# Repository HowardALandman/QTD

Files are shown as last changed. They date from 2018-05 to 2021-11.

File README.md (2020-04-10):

# QTD
Research project on Quantum Time Dilation, including theory and plans for an experiment to test it.
For theory, see the doc/QuantumTime.pdf (or .tex) file, and the references therein.
For photos, see FB album https://www.facebook.com/howard.a.landman/media_set?set=a.10153244377383214.1073741833.690298213&type=3 .

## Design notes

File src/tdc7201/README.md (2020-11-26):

# TDC7201 driver for Raspberry Pi

This project contains a python3 module for interfacing with the Texas Instruments TDC7201 Time-to-Digital-Converter chip through SPI.
As much as possible, it hides the internal implementation details (like SPI transactions, and chip registers and their field encodings) from the user.

All code is GPLv3+ licensed unless explicitly stated otherwise.

For more information on the chip, see https://www.ti.com/product/TDC7201

## Usage

```python
import tdc7201
tdc = tdc7201.TDC7201() # Create TDC object with SPI interface.
tdc.initGPIO() # Set pin directions and default values for non-SPI signals.
tdc.set_SPI_clock_speed(12500000)
tdc.on()
tdc.configure(meas_mode=2,num_stop=3,clock_cntr_stop=1,timeout=0.0005)
status = tdc.measure(simulate=True)
tdc.off()
```

## Settings

Hardware pin assignments are done in `initGPIO()`, which should only be called once.
Most other important parameters are set in the `configure()` method;
note that the chip can only be (re)configured while it is on.

## Methods

    initGPIO(enable=12,osc_enable=16,trig1=7,int1=37,trig2=11,int2=32,start=18,stop=22,verbose=False)

Assigns and initializes all the non-SPI pins.
Your actual hardware (wiring between RPi and chip) needs to match this setup.
No arguments are required, but the defaults match my prototype and are somewhat arbitrary.
You can see all assignments by calling with `verbose=True`.
Pin numbers follow `GPIO.BOARD` conventions,
i.e. they are the pin numbers on the 2x20 pin header.
Only 3 pins (`enable`,`trig1`,`int1`) are absolutely required;
the others can be skipped by assigning `None` to them.
If `osc_enable` is `None`, then there will be no signal to turn an external clock on or off; this is OK if you supply the chip clock yourself.
If `trig2` and/or `int2` is `None`, then side 2 of the chip will not work correctly, but side 1 still will.
The `stop` pin is only required if you want the Raspberry Pi to generate STOP signals for testing, i.e. if you plan to run `tdc.measure(simulate=True)`.
If you are hooked up to real signals to measure, then you can and should set `stop=None`.
The `start` pin is only required if you want the Raspberry Pi to generate a START signal; this could be hooked directly to the chip START, or used to trigger some external hardware.
Note that if you start a measurement, and the chip never sees a START signal, it will hang indefinitely waiting for one.

    on()

Takes the chip out of reset.

    configure(side=1,force_cal=True,meas_mode=2,trig_falling=False,falling=False,calibration2_periods=10,avg_cycles=1,num_stop=1,clock_cntr_stop=0,clock_cntr_ovf=0xFFFF,timeout=None)

Set up various control parameters in the chip configuration registers.

* `side` -
Which side of the chip to configure. Default is 1. 2 does not work yet.
* `retain_state` -
Default `False`.
If `True`, will ignore all other arguments, and instead use the same settings
as from the previous call to `on()`.
Behavior is undefined if there was no previous call.
* `force_cal` -
If `True`, will recalibrate the chip after every attempted measurement.
This is recommended (and, in this version, required and default).
If `False`, will only recalibrate after a "successful" measurement,
with timeouts and some other results considered unsuccessful.
(This currently does not work.)
* `meas_mode` -
Sets the measurement mode.
Mode 1 is recommended for times less than 2000 nS; mode 2 for greater.
* `trig_falling` -
If `True`, sets the chip to use falling edge on TRIG to indicate chip is ready.
The default is `False`, which has it use rising edge on TRIG.
* `falling` -
If `True`, sets the chip to trigger on falling edges of START and STOP.
The default is `False`, which has it trigger on rising edges.
* `calibration2_periods` - The number of clock cycles to recalibrate for. The allowed values are 2, 10 (hardware default), 20, and 40.
If you specify any other value, will round up (if below 40) or down (if above 40) to the next legal value.
* `avg_cycles` -
The number of measurements to average over.
The allowed values are 1, 2, 4, 8, 16, 32, 64, and 128.
The default is 1, which means no averaging.
If you use anything larger, the chip will run that many measurements and then report only the average values.
This can be useful in a noisy environment.
(Averaging does not currently work with `measure(simulate=True)`.)
* `num_stop` -
The chip starts timing on a pulse on the START pin, and then can record timings for up to 5 pulses on the STOP pin.
Allowed values are 1, 2, 3, 4, 5.
The default is 1, which means the measurement will terminate as soon as a single STOP pulse is received.
If `num_stop==3`, the measurement will terminate after recording 3 STOP pulses or after timing out, whichever comes first.
* `clock_cntr_stop = N` - If N is non-zero, the chip will ignore STOP pulses for N clock cycles after START.
* `clock_cntr_ovf = N` - The chip will end measurement ("time out" or "clock counter overflow") after N clock cycles even if `num_stop` STOP pulses have not been received.
Default (and maximum) is 65535 = 0xFFFF.
* `timeout = T` - You can also specify the overflow period as a time in seconds. For example, if T is 0.0005, the timeout period will be 500 microseconds. If both `timeout` and `clock_cntr_ovf` are specified, `timeout` wins.

Note that `clock_cntr_ovf` must be greater than `clock_cntr_stop`,
or the measurement will time out before it begins accepting stop pulses.

    measure(simulate=False,error_prefix='',log_file=None)

Runs a single measurement, waiting for the chip INT1 pin to go low indicating completion.
Will time out after 1 or more milliseconds if measurement doesn't complete.
(The `measure()` timeout must be an integer number of mS,
and is adjusted to be longer than the timeout set for the chip.)
If `simulate=True`, then generates START and/or STOP signals to send to the chip
(for testing when your actual signal source is not yet available);
this requires that the appropriate RPi pins be connected to START and/or STOP,
and that `initGPIO()` not be called with `start=None` or `stop=None` respectively.
(Simulate does not currently work with averaging.)
If it does complete, calls `read_regs24()` to download the raw register data,
and then `count_pulses()`.
The `error_prefix` string will be prepended to any error messages from this call to `measure()`;
this allows you to easily identify which call had the problem.
If `log_file` is an already-open file handle,
will write any error messages to that file instead of printing them.
Returns 0-5 for number of pulses seen, or 6-13 for various kinds of errors.

    compute_tofs()

Takes the raw register data dowloaded by the last measurement
and computes the time-of-flight for each pulse seen,
leaving them in the `tdc.tof1` to `tdc.tof5` variables.
Returns 0 to 5 for the number of pulses seen,
or 6 if an error prevented the computation.

    count_pulses()

Examines the raw register data dowloaded by the last measurement
and returns 0 to 5 for the number of pulses seen,
or 6 if an error prevented the computation.
This is about 8 times faster than `compute_tofs()`,
because it does less work.

    off()

Asserts reset and waits 1 uS for it to take effect.
This will terminate any measurement in progress,
and make the chip unresponsive to SPI until the next call to `on()`.

    clear_status(verbose=False,force=False)

Clears any set interrupt status register bits to prepare for next measurement.
This isn't supposed to be necessary, but I was having problems without doing it.
If `verbose==True`, prints detailed step-by-step results for debugging.
If `force==True`, tries to clear all IS bits even if some or all of them appear not to be set.

    set_SPI_clock_speed(speed,force=False)

Attempts to set the SPI interface clock speed to `speed` (in Hz).
Minimum legal value is 50000 (50 kHz), spec maximum is 25000000 (25 MHz),
and highest "overclocked" speed we've seen work is 33300000 (33.3 MHz).
The SPI clock is a hardware division of the CPU clock, so there are two important things to note.
(1) The exact clock speed set may be restricted (by hardware) to only certain values in that range, so you may not get exactly what you ask for.
(2) The SPI clock will slow down or speed up if the CPU clock does (for example, for thermal management, turbo mode, or due to user over- or under-clocking of the Raspberry Pi).
 The CPU (and the SPI driver, and this module) can not tell what the CPU clock speed is, so there is no way to compensate for this in software.
Therefore, it's probably a bad idea to overclock the SPI speed
if you know that your CPU will also be overclocked,
since that might result in a speed that doesn't work.
But all this should mostly be invisible to the user, as it only affects SPI communication speed, and does not affect performance of the TDC7201 measurements (unless the TDC7201 is also being clocked by some submultiple of the Pi clock, which is a really really bad idea).
* If `force=False`, values in the spec range are silent,
and overclocking up to 33.3 MHz is allowed with a warning.
If `force=True`, all speeds are allowed with a warning.
This should only be used for testing, not production.

The casual user should be able to get by with only the above methods; the following low-level methods give more detailed access to the hardware, but you'll need to know what you're doing.

    write8(reg,val)

Write a single 8-bit value to an 8-bit chip register.
This only makes sense for 8-bit registers (addresses 0 through 9).

    read8(reg)

Read a single 8-bit value from an 8-bit chip register.
This only makes sense for 8-bit registers (addresses 0 through 9).

    write16(reg,val)

Write a 16-bit value to a pair of 8-bit registers.
This only makes sense if reg is `COARSE_CNTR_OVF_H` (4), `CLOCK_CNTR_OVF_H` (6), or `CLOCK_CNTR_STOP_MASK_H` (8).

    read16(reg)

Read a pair of 8-bit registers and return them as a 16-bit value.
This only makes sense if reg is `COARSE_CNTR_OVF_H` (4), `CLOCK_CNTR_OVF_H` (6), or `CLOCK_CNTR_STOP_MASK_H` (8).

    write24(reg,val)

Write a 24-bit value to a 24-bit chip register.
This should probably never be used since those contain measurement and calibration results.

    read24(reg)

Read a 24-bit value from a 24-bit chip register.
This only makes sense for 24-bit registers (addresses 16 through 28).

    read_regs8()

Read all of the 8-bit side 1 chip registers into the `tdc.reg1` list.
(It should be possible to make this read the side 2 registers, but it doesn't yet.)
This is much faster than looping over the registers in Python.

    read_regs24()

Read all of the 24-bit side 1 chip registers (measurement and calibration results) into the `tdc.reg1` list.
(It should be possible to make this read the side 2 registers, but it doesn't yet.)
This is much faster than looping over the registers in Python.

    read_regs()

Read all of the side 1 chip registers (including measurement results) into the `tdc.reg1` list.
(It should be possible to make this read the side 2 registers, but it doesn't yet.)
This is much faster than looping over the registers in Python.
Equivalent to `read_regs8()` plus `read_regs24()`.

    print_regs1()

Print the internal copy of the side 1 chip registers. Note that, if this is not immediately preceded by `read_regs()`, the internal copy and the actual chip registers may be out of sync.

    tof_mm1(time_n)

Compute time-of-flight in seconds using Measurement Mode 1 equation.

    tof_mm2(time1,time_n,count)

Compute time-of-flight in seconds using Measurement Mode 2 equations.

    compute_tofs()

Check how many pulses we got, and compute the TOF for each pulse.

    cleanup()

Put the TDC7201 into reset, close the SPI device, and free all the GPIO pins.
Should normally only be called just before exiting.
The tdc object will still exist,
but you would have to manually reopen `tdc._spi` and set its parameters,
plus call `initGPIO()` and `on()`,
before it would be usable again.

    exit()

Clean up the SPI and GPIO pins (i.e. call `cleanup()`), and then exit.

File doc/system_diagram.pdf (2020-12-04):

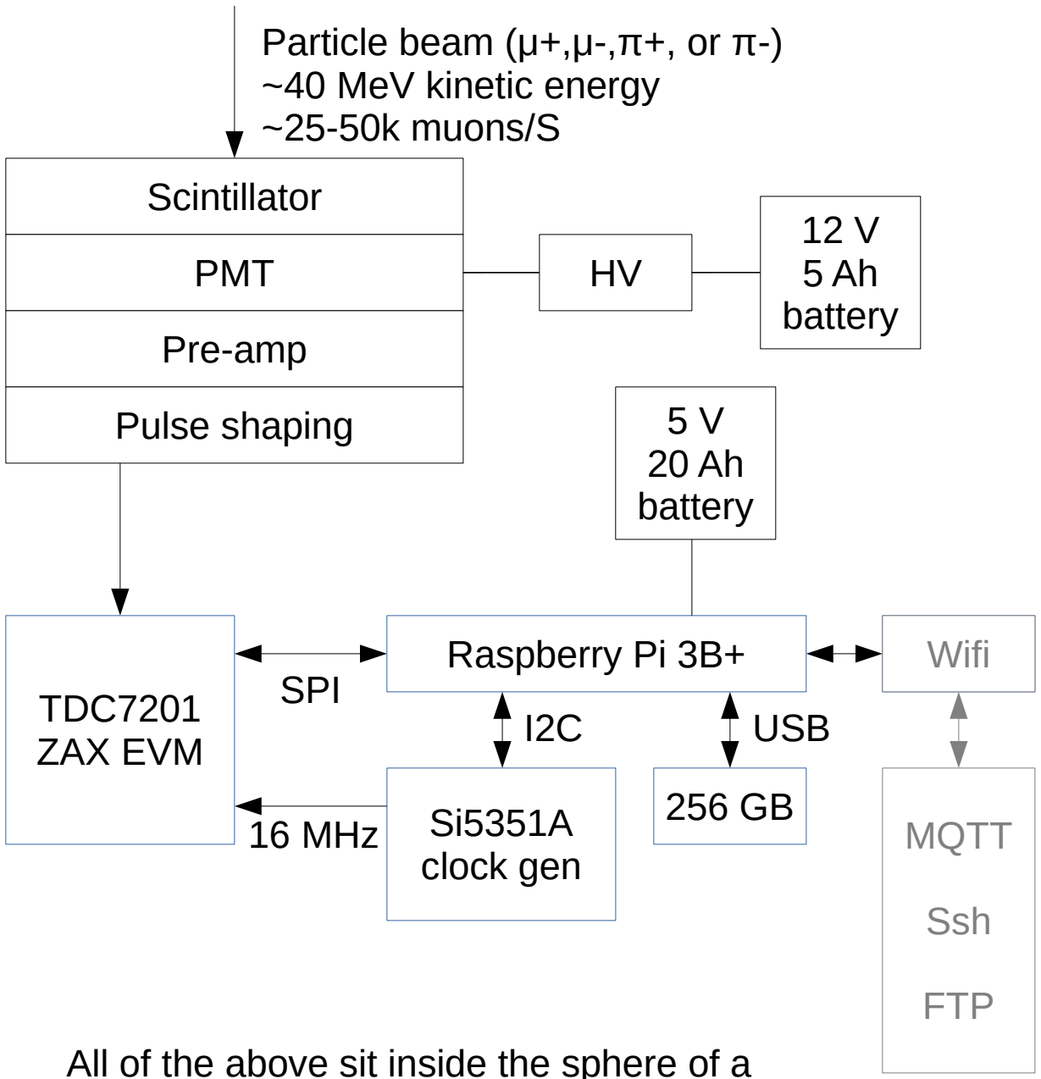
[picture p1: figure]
Particle beam (μ+,μ-,π+, or π-) ~40 MeV kinetic energy ~25-50k muons/S; Scintillator; PMT; Pre-amp; Pulse shaping; 12 V 5 Ah battery; TDC7201 ZAX EVM; Raspberry Pi 3B+; SPI; 5 V 20 Ah battery; Si5351A clock gen; 16 MHz; MQTT; Ssh; FTP; Wifi; USB

All of the above sit inside the sphere of a Van De Graaff generator, except for the external wifi router and things connected through it.

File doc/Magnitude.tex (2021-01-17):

%%%%%%%%%%%%%%%%%%%%%%% file template.tex %%%%%%%%%%%%%%%%%%%%%%%%%
%
% This is a general template file for the LaTeX package SVJour3
% for Springer journals.          Springer Heidelberg 2010/09/16
%
% Copy it to a new file with a new name and use it as the basis
% for your article. Delete % signs as needed.
%
% This template includes a few options for different layouts and
% content for various journals. Please consult a previous issue of
% your journal as needed.
%
%%%%%%%%%%%%%%%%%%%%%%%%%%%%%%%%%%%%%%%%%%%%%%%%%%%%%%%%%%%%%%%%%%%
%
% First comes an example EPS file -- just ignore it and
% proceed on the \documentclass line
% your LaTeX will extract the file if required
\begin{filecontents*}{example.eps}
%!PS-Adobe-3.0 EPSF-3.0
%%BoundingBox: 19 19 221 221
%%CreationDate: Mon Sep 29 1997
%%Creator: programmed by hand (JK)
%%EndComments
gsave
newpath
  20 20 moveto
  20 220 lineto
  220 220 lineto
  220 20 lineto
closepath
2 setlinewidth
gsave
  .4 setgray fill
grestore
stroke
grestore
\end{filecontents*}
%
\RequirePackage{fix-cm}
%
%\documentclass{svjour3}                     % onecolumn (standard format)
%\documentclass[smallcondensed]{svjour3}     % onecolumn (ditto)
\documentclass[smallextended]{svjour3}       % onecolumn (second format)
%\documentclass[twocolumn]{svjour3}          % twocolumn
%
\smartqed  % flush right qed marks, e.g. at end of proof
%
\usepackage{graphicx}
%
% \usepackage{mathptmx}      % use Times fonts if available on your TeX system
%
% insert here the call for the packages your document requires
%\usepackage{latexsym}
% etc.
%
% please place your own definitions here and don't use \def but
% \newcommand{}{}
%
% Insert the name of "your journal" with
\journalname{International Journal of Theoretical Physics}
%
\begin{document}

\title{The magnitude of electromagnetic time dilation%\thanks{Grants or other notes
%about the article that should go on the front page should be
%placed here. General acknowledgments should be placed at the end of the article.}
}
%\subtitle{Do you have a subtitle?\\ If so, write it here}

%\titlerunning{Short form of title}        % if too long for running head

\author{Howard A. Landman}
% ORCID: 0000-0003-1897-0112

%\authorrunning{Short form of author list} % if too long for running head

\institute{H. A. Landman \at
              Fort Collins, Colorado, USA \\
              Tel.: +1-970-980-1660\\
              \email{howard@riverrock.org}\\
              ORCID: 0000-0003-1897-0112           %  \\
%             \emph{Present address:} of F. Author  %  if needed
}

\date{Received: date / Accepted: date}
% The correct dates will be entered by the editor

\maketitle

\begin{abstract}
Theories unifying gravity and electromagnetism naturally give rise to the question
of whether there is a time-dilation-like effect associated with the electromagnetic 4-potential.
This notion has been widely rejected, but a handful of theories explicitly predict such an effect. \cite{Apsel1978,Apsel1979,Apsel1981,Rodrigues1983,Ryff1985,Beil1987,vanHolten1992}
At least to first order, all of them agree on its magnitude, but it has not been clear why.
Here, we show that the magnitudes of both gravitational and EM time dilations
can be computed from elementary considerations
($E=h\nu$ and $E=mc^2$)
that are independent of specific unified theories.
This demonstrates that EM time dilation must be a feature of any unified theory
that is compatible with both Special Relativity and Quantum Mechanics.
\keywords{time dilation \and gravitational \and electromagnetic \and muon \and pion \and potential}
\PACS{03.65.Sq \and 04.50.+h \and 12.10.-g \and 12.39.Pn \and 12.60.-i \and 13.35.Bv}
% \subclass{MSC code1 \and MSC code2 \and more}
\end{abstract}

\section{Introduction}
\label{intro}

From the first publication of General Relativity in 1915 to about 1930, hundreds of classical theories
were proposed attempting to unify gravity and electromagnetism \cite{Vizgin1994}.
While none of these was completely successful, some of them were very influential.
For example, Weyl's Space-Time-Matter theory \cite{Weyl1923} introduced the notion of gauge invariance,
while Kaluza-Klein theory \cite{Kaluza1921,Klein1926} used a compact 5th dimension
and was an important precursor to string theory.

Given that there is a time dilation associated with the gravitational potential in GR,
it seems reasonable to wonder whether there might be a similar time-dilation-like effect
associated with the EM potential in such unified theories.
Sadly, this question has rarely been asked, let alone answered.
David Apsel in 1978-1981 gave probably the first unified theory to explicitly predict such a time dilation \cite{Apsel1978,Apsel1979,Apsel1981},
and only a handful of subsequent papers \cite{Rodrigues1983,Ryff1985,Beil1987,vanHolten1992} mention anything similar.
At least to first order,
all of these theories agree on the magnitude of EM time dilation.

Here we show why they must.
We derive the magnitudes of both gravitational and electromagnetic time dilations
from elementary considerations ($E=h\nu$ and $E=mc^2$)
that do not depend on the machinery of GR or any specific unified theory,
and thereby demonstrate that they must be features
of any unified theory that is compatible with both Special Relativity and Quantum Mechanics.

\section{History}
\label{sec:2}

Einstein first derived gravitational time dilation in his 1907 paper on the Relativity Principle \cite{Einstein1907}.
He began in \S 18 by using Special Relativity to show that clocks at different X-positions in a reference frame accelerated in the X-direction cannot run at the same rate;
then in \S 19 used the Equivalence Principle to infer that the same thing must be true
for clocks at different values of a gravitational potential $\Phi$.
He carried out all the arguments to first order to give the linear form $T_d = 1 + \Phi/c^2$, which has since become called the weak-field approximation,
although he did note in passing that the actual formula must be
%exponential in form
$T_d = {\rm e}^{\Phi/c^2}$.
The linear approximation cannot be exactly correct because it has two problems:
it is logically inconsistent since $(1+\Phi/c^2)(1-\Phi/c^2) \ne 1$,
and there is an event horizon at $\Phi = -c^2$.
The exponential form solves both of those problems.
%We emulate his linearized first-order approach in what follows,
%but return later to briefly consider the non-linear form.

The conclusion of the 1907 argument is that acceleration
causes the rate of time flow to be a function of position
in the direction of the acceleration.
It did not matter to Einstein whether the acceleration was caused by a rocket,
or by standing on the ground in a gravitational field.
%or by being attached to a spinning disk.
Although he didn't mention it,
it is worth noting that the acceleration of a charged particle by an electric field
is not immune to this argument.
Neither are accelerations due to the weak and strong forces;
\textit{all} accelerations of a given magnitude
\textit{must} cause exactly the same time dilation.

After General Relativity in 1915 and the Schwarzschild solution in 1916,
another view became possible,
although it is still not widely appreciated.
Taking the weak field ($r_s \ll r$) and low speed ($\frac{{\rm d}r}{{\rm d}t} \ll c$) limit of the Schwarzschild metric
leaves us with the Newtonian metric
\begin{equation}
{\rm d}s^2 = ({\rm d}x^2 + {\rm d}y^2 +{\rm d}z^2 - c^2{\rm d}t^2) + (-2\frac{GM}{r}){\rm d}t^2
\end{equation}
which is just flat Minkowski spacetime plus the time dilation field.
In this metric, space is completely flat and only time is curved,
and the curved time gives geodesics that match Newtonian gravity.
This pure time dilation field appears as a $1/r^2$ ``force''.
So in the Newtonian limit of GR,
%``matter tells time how to dilate, and time dilation tells matter how to move''.
matter causes a time dilation field and the time dilation gradient causes gravitational acceleration.\footnote{This line of thought was anticipated by several early unified theories,
although they tended to describe it as a speed-of-light field rather than a time dilation field.
For example, Ishiwara wrote in 1912 that
"if the speed of light varies in space and in time,
then these variations lead to the appearance precisely there of a gravitational field." \cite{Ishiwara1912}}
The direction of cause and effect is completely reversed from the 1907 argument.

If we accept both of these arguments,
then we cannot have any acceleration without an associated time dilation gradient,
and we cannot have any time dilation gradient without an associated acceleration.
The two are inextricably linked.

\section{Gravitational time dilation from $E = h\nu$ and $E = mc^2$}
\label{sec:3}

In this section we use a new method
to derive gravitational time dilation without directly invoking relativity theory.
We assume only that particles have a rest energy associated with their mass, given by $E = mc^2$,
and a frequency associated with their energy, given by $E = h\nu$.

In a uniform gravitational field of strength $g$, raising a particle by a height $z$ requires work $mgz$. Thus, to an observer at height $0$, the total energy of the particle at height $z$ is given by $E(z) = mc^2 + mgz$ and its frequency by $\nu(z) = E(z)/h$.

However, an observer already at height $z$ would perceive the particle to have merely frequency $\nu(0) = mc^2/h$. This can only be true if the two observers have clocks running at different rates, in the ratio

\begin{equation}
T_d = \frac{\nu(z)}{\nu(0)} = \frac{E(z)}{E(0)} = \frac{mc^2 + mgz}{mc^2} = 1 + \frac{gz}{c^2}
\end{equation}

\noindent which is the weak-field approximation to GR's gravitational time dilation
(with $\Phi = gz$).
As above, the linear form can't be exactly correct but the exponential form
$T_d = {\rm e}^{gz/c^2}$ is.

This derivation appears in some sense to be quantum, since it utilizes $E = h\nu$.
But because time dilation is a dimensionless ratio, $h$ cancels out and its precise value doesn't matter.
This means that the classical ($h \to 0$) limit is exactly the same as the ``quantum'' result.
% Should perhaps discuss Colella-Overhauser-Werner experiment here.

Both this derivation and Einstein's 1907 one avoid almost all the assumptions of GR,
so each of them implies that any other theory that predicts a gravitational time dilation
must have the same relation of dilation to potential as GR.
From this viewpoint, the existence and magnitude of gravitational time dilation
cannot be viewed as a confirmation of GR specifically,
but only of a class of theories of which GR is the best known example.

%There is a curious paradox hidden in the above results.
%$\nu = E/h$ implies that in QM the (quantum phase) frequency of things is linearly proportional to their energy.
%$T_d = e^{ gz/c^2 } = e^{ mgz/mc^2 }$ implies that in GR
%the (time-dilated) frequency of things is an exponential function of their energy.
%Both formulae are widely accepted, but
%it seems obvious that they cannot both be universally true.
%Reconciling this apparent contradiction is beyond the scope of the current paper.

\section{Electromagnetic time dilation by the same method}
\label{sec:4}

We now consider the case of a particle with mass $m$ and charge $q$ in an electrostatic potential $V$.
The potential energy is $qV$, so the corresponding time dilation (to first order) must be
\begin{equation}
T_d =  \frac{mc^2 + qV}{mc^2} =  1 + \frac{qV}{mc^2}
\end{equation}
This is essentially Apsel's equation \cite{Apsel1979}
\begin{equation}
\tau_0 =  \left(1 + \frac{q}{mc^2} {\bf A}_\mu {\bf u}^\mu \right) t_0
\end{equation}
but it is achieved without any recourse to tensor calculus
or dependence on any particular unified theory.

As in the gravitational case,
the linear form cannot be completely right, and
the exponential form 
\begin{equation}
T_d = {\rm e}^{qV/mc^2}
\end{equation}
is the most obvious candidate to replace it.
But unlike in the gravitational case, here both charge and mass matter,
or more precisely the dilation is a function of the charge/mass ratio $q/m$.
This means that a simple Riemannian manifold is inadequate,
and the geometry of any unified theory has to be something more complicated,
like a Finsler space. \cite{Beil1987}

One could argue that this is not a true time dilation,
since it does not affect "time itself" (i.e. the local speed of light),
but only what gets measured by particular kinds of clocks (charged particles).
Thus, it might be more reasonable to describe it as a "potential-based time-dilation-like effect."
Much of the universal character of gravitational time dilation is absent.

However, a different kind of universality is gained,
in that the unified time dilation equation
(ignoring gravitomagnetic and magnetic terms) is
\begin{equation}\label{emtd}
T_d \approx  {\rm e}^{(m\Phi + qV) / mc^2}
\end{equation}
which treats gravity and EM equally and symmetrically.
In fact, all known and unknown forces can easily be slotted into the general equation
\begin{equation}\label{qtd}
T_d \approx  {\rm e}^{(m\Phi + qV + wW + sS + xX) / mc^2}
\end{equation}
where $w$ and $W$ are the weak force charge and potential respectively,
$s$ and $S$ the strong force ones,
and $x$ and $X$ those of some as-yet-undiscovered force
as long as it is conservative and can be represented by a potential.
This symmetry makes it more reasonable to refer to all of these effects by the same name,
"time dilation".

The claim that there are time dilations associated with all fundamental potentials
was first made by Apsel \cite{Apsel1978,Apsel1979},
but it can be considered a simple and direct consequence of QM treating all potential energies equally.
Thus we call the claim that all potentials have an associated time-dilation-like effect Quantum Time Dilation or QTD.
The weaker claim that this is at least true for EM we call Electromagnetic Time Dilation or EMTD.

\section{How to test for EMTD}
\label{sec:5}

Uncharged particles should be completely unaffected.
For a given non-zero $q$, lighter particles will be dilated more strongly than heavier particles.
The electron, being the lightest charged particle and having the highest charge/mass ratio,
should be affected the most.
But since electrons have infinite lifetime,
the only observable effect on them is the shift in phase frequency.
Although this is universally observed,
most physicists would not consider it proof of or even evidence for EMTD.

Thus, for experimental testing, we are lead to the muon.
With a mass-energy of $m_\mu c^2 = 105.7\ \textup{MeV}$,
it is still light enough to have its mean lifetime of $2.2\ \mu \textup{S}$
affected by a modest potential.
For example, a potential of 1.057 MV should alter its lifetime by about 1\%.
Traditional Van de Graaff generators have achieved voltages in the range of
0.33 to 1.4 MV per meter diameter, with 1.0 being perhaps typical,
so such a potential could be achieved
% by a Van de Graaff generator
with a sphere of about 0.7-1.1 m diameter in air,
which is well within reach of a serious hobbyist.
Apsel first proposed this kind of experiment in 1979 \cite{Apsel1979};
41 years later it still has never been performed.

For static magnetic interactions, the potential energy is $-\vec{\mu}\cdot\vec{B}$,
where $\vec{\mu}$ is the magnetic moment and $\vec{B}$ is the magnetic field,
and so to first order we get
\begin{equation}\label{mtd}
T_d =  1 + \frac{-\vec{\mu}\cdot\vec{B}}{mc^2}
\end{equation}
The muon's measured magnetic moment is
$\mu = -4.49 \times 10^{-26}\ \textup{J}/\textup{T}$.

Van Holten was the first to analyze this magnetic effect in isolation,
and thought that detection using muons might only require $5 \times 10^9\ \textup{T}$,
which could be found in the vicinity of a magnetar \cite{vanHolten1992}.
Since this is field- and not potential-based,
it should be a less controversial claim than full EMTD.
But given that the world record magnetic fields are in the range of 45--330 T,
this seems far beyond the reach of current Earth-based experiment.
%Only the electrostatic part of the effect is amenable to testing.
Indeed, to get the same 1\% level of relative time dilation between spin-up and spin-down muons,
we would need to place them in a field of
\begin{equation}
1.057\ \textup{MeV} \times \frac{1\ \textup{J}}{6.24\times 10^{12}\ \textup{MeV}} \times \frac{1\ \textup{T}}{2 \times (4.49 \times 10^{-26}\ \textup{J})} \approx 1.89 \times 10^{12}\ \textup{T}
\end{equation}
Thus, here we advocate for testing the electrostatic effect.
Dynamic interactions offer other possibilities, however \cite{Apsel1979}.

%Negative muons ($\mu^-$) bound to low-Z nuclei are also known to have lengthened lifetimes.
%The normal explanation for this is that the muon has a kinetic energy given by the quantum virial theorem,
%and an average velocity corresponding to that kinetic energy,
%and a special-relativistic time dilation corresponding to that velocity.
%However, Apsel has argued that this calculation does not match the experimental data very well,
%and that adding a (smaller) electromagnetic time dilation term gives a better fit \cite{Apsel1981}.
%If so, we may have already been seeing evidence for decades.
%The effect should be more obvious for higher Z.
%Unfortunately, as Z increases, nuclear capture by a proton begins to dominate,
%and we don't have good data on non-capture decay rates for most elements.

One characteristic of a pure time dilation is that, all other things being equal,
it must necessarily slow down (or speed up) all decay modes equally.
Since muons have 3 known decay modes \cite{PDG2014}, this can be used as a test
for whether lifetime alterations can reasonably be viewed as solely due to time dilation,
or whether other factors must be invoked.

Charged pions ($\pi^+$, $\pi^-$) have a charge-mass ratio 0.757 as large as a muon's,
and would also be reasonable for such experiments, but would require about
$0.757^{-2} = 1.745$ times as many data points to get the same statistical significance.

\section{Counterarguments}
\label{sec:6}

In this section we point out flaws in two of the main counterarguments to EM time dilation.

\subsection{Naive Gauge Invariance.}

In many physical theories,
such as classical EM and Van Holten's theory mentioned in the previous section,
everything can be expressed in terms of fields acting locally,
and potentials can be viewed as having no physical reality but being merely aids to computation.
This would of course rule out any time dilation effects from an EM potential in a field free region,
such as inside the sphere of a Van De Graaff generator.
Many physicists seem to think that this is sufficient to disprove the theory.

%The standard counterargument is that the gauge invariance of most modern theories makes the proposed effect impossible.
The problem with this viewpoint is that it is flat-out wrong.
The universe does \textit{not} have that property;
the Aharonov-Bohm effect \cite{Ehrenberg1949,Aharonov1959} suffices as a counterexample.
The importance of this is often glossed over.
For example, Jackson and Okun \cite[p.24]{Jackson2001} write:
\begin{quote}
\ldots\ gauge invariance is a manifestation of non-observability of $A_\mu$.
However integrals \ldots\ are observable when they are taken over a closed path, as in the Aharonov-Bohm effect \ldots\@
The loop integral of the vector potential there can be converted by Stokes's theorem into the magnetic flux through the loop,
showing that the result is expressible in terms of the magnetic field, albeit in a nonlocal manner.
%It is a matter of choice whether one wishes to stress the field or the potential, but the local vector potential is not an observable.
\end{quote}
Contrast this with the discussion in Feynman Vol. II \cite{FeynmanII} lecture 15-5,
where the central importance of the potential is
%emphasized: % American English
emphasised: % British English
\begin{quote}
The fact that the vector potential appears in the wave equation of quantum mechanics
(called the Schr\"{o}dinger equation)
was obvious from the day it was written.
That it cannot be replaced by the magnetic field in any easy way
was observed by one man after the other who tried to do so.
This is also clear from our example
of electrons moving in a region where there is no field and being affected nevertheless.
But because in classical mechanics \textit{\textbf{A}} did not appear to have any direct importance and,
furthermore, because it could be changed by adding a gradient,
people repeatedly said that the vector potential had no direct physical significance ---
that only the magnetic and electric fields are ``right'' even in quantum mechanics.
It seems strange in retrospect that no one thought of discussing this experiment until 1956 \ldots
The implication was there all the time, but no one paid attention to it. \ldots\ 
It is interesting that something like this can be around for thirty years but,
because of certain prejudices of what is and is not significant,
continues to be ignored.
\end{quote}
In either case, the idea that fields acting locally can explain everything is admitted to be false.

It is also worth noting that gravitational time dilation itself is locally non-observable.
There is no contradiction in claiming that a locally non-observable potential
can have a locally non-observable effect;
this is precisely how gravitational time dilation works.
However the situation is different for EM time dilation.
Since the effect is a function of the charge/mass ratio,
the time dilation experienced by (say) a muon and a human observer
is predicted to be different at the same potential.
This makes EM time dilation (and the absolute electrostatic potential) locally observable.

\subsection{CPT Invariance.}

It is often stated (e.g. in \cite{Andreev2007,Murayama2003,Sachs1987}) that CPT symmetry
guarantees that particle and antiparticle masses and lifetimes are identical.
However, this conclusion is only justified at zero potential,
or with the further assumption of naive gauge invariance (which renders potential irrelevant).
A true CPT reflection must invert all charges and magnetic moments in the universe,
which necessarily inverts all EM potentials as well.
Therefore, the CPT theorem only \textit{really} proves that a particle's mass and lifetime at 4-potential \textbf{A} must equal its antiparticle's mass and lifetime at 4-potential -\textbf{A}.
This holds true under EM time dilation, since the dilations for those two cases are identical.
Thus, the CPT theorem does not contradict the claim that particles and antiparticles will be time-dilated oppositely at a non-zero potential and that their lifetimes will differ there.
EM time dilation is completely compatible with the notion of CPT invariance.

\section{Summary}
\label{sec:7}

We reviewed two early derivations of gravitational time dilation
and gave a new elementary derivation of it.
Both the 1907 Einstein derivation and this new method
can be trivially modified to give derivations of electromagnetic time dilation as well,
which agree in magnitude with the handful of prior theories predicting such an effect.
That EMTD seems so inescapably implied,
and is yet so widely rejected,
%(with multiple counter-arguments, albeit some flawed)
points perhaps to a deep paradox in current physical thought.
Since testing for the electrostatic effect would be quite easy and cheap,
it seems worthwhile to actually perform that experiment.

%\subsection{Subsection title}
%\label{sec:2}
%as required. Don't forget to give each section
%and subsection a unique label (see Sect.~\ref{sec:1}).
%\paragraph{Paragraph headings} Use paragraph headings as needed.
%\begin{equation}
%a^2+b^2=c^2
%\end{equation}

%% For one-column wide figures use
%\begin{figure}
%% Use the relevant command to insert your figure file.
%% For example, with the graphicx package use
%  \includegraphics{example.eps}
%% figure caption is below the figure
%\caption{Please write your figure caption here}
%\label{fig:1}       % Give a unique label
%\end{figure}
%%
%% For two-column wide figures use
%\begin{figure*}
%% Use the relevant command to insert your figure file.
%% For example, with the graphicx package use
%  \includegraphics[width=0.75\textwidth]{example.eps}
%% figure caption is below the figure
%\caption{Please write your figure caption here}
%\label{fig:2}       % Give a unique label
%\end{figure*}
%%
%% For tables use
%\begin{table}
%% table caption is above the table
%\caption{Please write your table caption here}
%\label{tab:1}       % Give a unique label
%% For LaTeX tables use
%\begin{tabular}{lll}
%\hline\noalign{\smallskip}
%first & second & third  \\
%\noalign{\smallskip}\hline\noalign{\smallskip}
%number & number & number \\
%number & number & number \\
%\noalign{\smallskip}\hline
%\end{tabular}
%\end{table}

%\begin{acknowledgements}
%If you'd like to thank anyone, place your comments here
%and remove the percent signs.
%\end{acknowledgements}

% Authors must disclose all relationships or interests that 
% could have direct or potential influence or impart bias on 
% the work: 
%

\section*{Declarations}

\subsection*{Funding}
Self

\subsection*{Conflicts of interest/Competing interests}
The author declares that he has no conflict of interest.

\subsection*{Availability of data and material}
Not applicable.
Earlier versions of the paper have been available on Vixra and ResearchGate.
All plans, source code, 3D designs, etc. for a planned experiment to test this class of theories
are available and under version control at https://github.com/HowardALandman/QTD/,
including versions of this and other papers.

\subsection*{Code availability}
Not applicable.
However https://github.com/HowardALandman/QTD/src/
contains software related to the experiment.

\subsection*{Authors' contributions}
I am the sole author.
I expect to acknowledge useful discussions with others in the final version,
but that may include reviewers,
so I have not written an acknowledgements section yet.

\subsection*{Ethics approval}
Not applicable.

\subsection*{Consent to participate}
Not applicable.

\subsection*{Consent for publication}
Not applicable.

% BibTeX users please use one of
%\bibliographystyle{spbasic}      % basic style, author-year citations
%\bibliographystyle{spmpsci}      % mathematics and physical sciences
%\bibliographystyle{spphys}       % APS-like style for physics
%\bibliography{}   % name your BibTeX data base

% Non-BibTeX users please use
\begin{thebibliography}{}

\bibitem{Vizgin1994}
Vizgin, V.P. (tr. Barbour J.B.):
Unified Field Theories in the First Third of the 20th Century.
Birkh\"{a}user Verlag, Switzerland (1994)

\bibitem{Weyl1923}
Weyl, H.:
Raum$\cdot$Zeit$\cdot$Materie, 6th ed.
%Springer-Verlag (18 Apr 1923)
Springer-Verlag, Berlin Heidelberg (1923)

%\bibitem{Weyl1923a}
%Ibid., pp. 304-305

\bibitem{Kaluza1921}
Kaluza, T.:
Zum Unit\"{a}tsproblem in der Physik.
Sitzungsber. Preuss. Akad. Wiss. Berlin (Math. Phys.), 966-972 (1921)
% Sitzungsberichte der Preussischen Akademie der Wissenschaften zu Berlin
 
\bibitem{Klein1926}
Klein, O.:
Quantentheorie und f\"{u}nfdimensionale Relativit\"{a}tstheorie.
Zeitschrift f\"{u}r Physik A. 37, 895-906 (1926)
%doi:10.1007/BF01397481.

\bibitem{Apsel1978}
Apsel, D.:
Gravitational, electromagnetic, and nuclear theory.
Int. J.  of Theoretical Physics 17, 643-649 (1978)
%DOI: 	10.1007/BF00673015

\bibitem{Apsel1979}
Apsel, D.:
Gravitation and electromagnetism.
General Relativity and Gravitation 10, 297-306 (1979)
%DOI: 10.1007/BF00759487

\bibitem{Apsel1981}
Apsel, D.:
Time dilations in bound muon decay.
General Relativity and Gravitation 13, 605-607 (1981)
%DOI: 10.1007/BF00757247

\bibitem{Rodrigues1983}
Rodrigues Jr., W.A.:
The Standard of Length in the Theory of Relativity and Ehrenfest Paradox.
Il Nuovo Cimento 74 B, 199-211 (1983)

\bibitem{Ryff1985}
Ryff, L.C.B.:
The Lifetime of an Elementary Particle in a Field.
General Relativity and Gravitation 17, 515-519 (1985)

\bibitem{Beil1987}
Beil, R.G.:
Electrodynamics from a Metric.
Int. J. of Theoretical Physics 26, 189-197 (1987).

\bibitem{vanHolten1992}
van Holten, J.W.:
Relativistic Time Dilation in an External Field.
Physica A: Statistical Mechanics and its Applications 182(1-2), 279-292 (1992)

%\bibitem{vanHolten1993}
%van Holten J.W.,
%``Relativistic Dynamics of Spin in Strong External Fields.'',
%Nationaal Inst. voor Kernfysica en Hoge-Energiefysica (NIKHEF), Amsterdam (Netherlands), Sectie H.
%Preprint at arXiv:hep-th/9303124v1 (1993)

%\bibitem{Dubey2015}
%Dubey A.K., Sen A.K.,
%``Gravitational Redshift in Kerr-Newman Geometry.'',
%\textit{Astrophys Space Sci} \textbf{360}, 29 (2015)

%\bibitem{Ogonowski2012}
%Ogonowski, P.,
%``Time dilation as field.'',
%\textit{Journal of Modern Physics}, \textbf{3}, 200-207 (2012)

\bibitem{Einstein1907}
Einstein, A.:
\"{U}ber das Relativit\"{a}tsprinzip und die aus demselben gezogenenn Folgerungen.
Jahrbuch der Radioaktivit\"{a}t und Elektronik 4, 411-462 (1907)
%English translation, ``On the relativity principle and the conclusions drawn from it'',
%\textit{The Collected Papers}, \textbf{2} 433-484 (1989),
%available at \url{https://einsteinpapers.press.princeton.edu/vol2-trans/319}

\bibitem{Ishiwara1912}
Ishiwara, J.:
Z\"{u}r Theorie der Gravitation.
Phys. Zeitschrift 15, 1189-1193 (1912),
translated by Barbour in Vizgin p.39.

\bibitem{PDG2014}
Olive, K.A., et al. (Particle Data Group):
Chin. Phys. C38, 090001 (2014)
%PDF at http://pdg.lbl.gov/2014/listings/rpp2014-list-muon.pdf.

\bibitem{Ehrenberg1949}
Ehrenberg, W., Siday, R.E.:
The Refractive Index in Electron Optics and the Principles of Dynamics.
Proc. Phys. Soc. B62, 8-21 (1949)
%DOI: 10.1088/0370-1301/62/1/303

\bibitem{Aharonov1959}
Aharonov, Y., Bohm, D.:
Significance of Electromagnetic Potentials in the Quantum Theory.
Phys. Rev. 115, 485-491 (1959)
%\url{http://link.aps.org/doi/10.1103/PhysRev.115.485}
%DOI: 10.1103/PhysRev.115.485

\bibitem{Jackson2001}
Jackson, J.D., Okun, L.B.:
Historical roots of gauge invariance.
Rev. Mod. Phys. 73, 663 (2001)

\bibitem{FeynmanII}
Feynman, R.P.:
Lectures on Physics II.
Addison Wesley (1964)

\bibitem{Andreev2007}
Andreev, V.A., et al.:
Measurement of the Rate of Muon Capture in Hydrogen Gas and 
Determination of the Proton's Pseudoscalar Coupling $g_P$.
Physical Review Letters 99(3), 032002 (2007)

\bibitem{Murayama2003}
Murayama, H.:
CPT Tests: Kaon vs Neutrinos.
Physics Letters B 597(1), 73-77 (2004)
%Preprint at arXiv:hep-ph/0307127 (2003)

\bibitem{Sachs1987}
Sachs, R.G.:
The Physics of Time Reversal, 175.
U. Chicago Press, Chicago London (1987)

%\bibitem{RefJ}
%% Format for Journal Reference
%Author, Article title, Journal, Volume, page numbers (year)
%% Format for books
%\bibitem{RefB}
%Author, Book title, page numbers. Publisher, place (year)
%% etc
\end{thebibliography}

\end{document}
% end of file template.tex

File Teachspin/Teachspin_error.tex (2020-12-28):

\documentclass[12pt]{amsart}
\usepackage{geometry} % see geometry.pdf on how to lay out the page. There's lots.
\geometry{a4paper} % or letter or a5paper or ... etc
% \geometry{landscape} % rotated page geometry
\usepackage{url}
\usepackage{amsthm}
\usepackage{listings}
\usepackage{graphicx}
 \lstset{
         basicstyle=\footnotesize\ttfamily, % Standardschrift
         numbers=left,               % Ort der Zeilennummern
         numberstyle=\tiny,          % Stil der Zeilennummern
}

% See the ``Article customise'' template for come common customisations

   % The amssymb package provides \mathbb and other
   % math symbols.  The amsmath package provides sophisticated math
   % constructions.  The amsthm package provides \theoremstyle and
   % the \proof environment.
   %
   % The amsmath and amsthm packages are automatically activated by
   % \documentclass{amsart}, so there is no need to activate them here.

      \usepackage{amssymb}

   % Next we use \newtheorem to specify our theorem-like environments
   % (theorem, definition, etc.) and how to display and number them.
   %
   % Note: The \theoremstyle declarations affect the appearance of the
   % Theorems, Definitions, etc.

      \theoremstyle{plain}
      \newtheorem{theorem}{Theorem}[section]
      \newtheorem{lemma}[theorem]{Lemma}
      \newtheorem{corollary}[theorem]{Corollary}
      
      \theoremstyle{definition}
      \newtheorem{definition}[theorem]{Definition}
      
      \theoremstyle{remark}
      \newtheorem{remark}[theorem]{Remark}

   % The preamble is also a good place to define new commands and macros.
   % This part of the preamble is strictly optional according to your taste.

      \newcommand{\R}{{\mathbb R}}
      \newcommand{\nil}{\varnothing}

   % The following mysterious maneuver gets rid of AMS junk at the top
   % and bottom of the first page.
   
      \makeatletter
      \def\@setcopyright{}
      \def\serieslogo@{}
      \makeatother

\title{Suitability of the Teachspin muon lifetime device for testing QTD}
\author{Howard A. Landman}
\date{} % delete this line to display the current date

%%% BEGIN DOCUMENT
\begin{document}

\maketitle
\tableofcontents

\section{Introduction}
D. Apsel\cite{Apsel1978,Apsel1979,Apsel1981} and I\cite{Landman2012}, by entirely different methods,
both reached theories that predict the lifetime of an unstable particle can be altered by changing its energy.
I call this effect Quantum Time Dilation (QTD).
In particular, both of us predict that muon lifetime will be altered by an electrostatic potential to the extent of about 1\% per 1.05 MV.
This is clearly a testable assertion, but is sufficiently outside the mainstream of current physics research that it could be difficult to obtain funding from the usual sources to test it.
In the hope of keeping the cost of testing as low as possible,
I explore whether an inexpensive commercial student-grade muon lifetime apparatus can,
or can be modified to, provide a sufficiently accurate measure of muon lifetime to conclusively falsify or confirm these theories.

\section{The Teachspin device}
The Teachspin muon lifetime device\cite{Coan2006,Teachspin} is self-contained
except for needing an electrical outlet
and an external (Windows or Linux) computer to store and display data and run the user interface software.
It has three main components.
\subsection{The scintillator cylinder}
The primary detector comprises a solid transparent cylinder of scintillator-doped polyvinyltoluene,
a single photo-multiplier tube (PMT),
a high-voltage power supply for the PMT,
and an amplifier that converts the PMT current output to a voltage signal.
These are all contained in a light-tight aluminum shell
which keeps out external photons that could cause experimental noise or even damage the PMT,
and also keeps the high PMT voltage safely away from users.
The shell also includes an LED circuit for creating artificial light pulses to test the PMT independently of particles,
and some control knobs for the LED and the PMT.
I did not use the LED feature.

Charged cosmic ray particles, mostly muons, strike the cylinder and can generate photons in the scintillator.
Since cosmic rays have very high momenta (up to about 4 GeV/c)
and the cylinder is relatively small with low stopping power
(the manual says 120 MeV/c; our simulations using SRIM/TRIM software\cite{SRIM} gave about 62-70 MeV),
most (about 97\%) of the particles pass through the scintillator without stopping.

\subsection{The discriminator and counter}
Most of the active electronics is contained in a separate chassis.
It includes a discriminator circuit with adjustable threshold,
that can be tuned to reject pulses below the threshold.
This produces an amplified "digital" pulse if the input "analog" pulse exceeds the threshold.
The digital pulse has fixed height, but its width varies with the width of the analog pulse.

The digital pulse is then fed into an FPGA, which starts a lifetime count if one isn't already running.
Since the FPGA runs on a 50 MHz (20 nS) clock,
it is incapable of distinguishing times any shorter than that.
The count runs for 1000 clock cycles (20 $\mu$S);
if a second pulse is seen in that time, it is counted as a decay event, otherwise it is counted as a transit event.

Once a second, the number of events in the last second is written out, along with any decay events.
Each decay event, and each event summary, is communicated via USB to the computer.

\subsection{Computer and software}
Software running on the host computer writes one line of text to the data file
for each decay event, and one for each event summary.
These are the only kinds of data in the files.

For summary records, the number of events seen is recorded, followed by a timestamp.
Consecutive timestamps differ by one.

For decay events, the time between pulses in nS is written,
and is always a multiple of 20 since it is computed by multiplying the raw count from the FPGA by the nominal clock period.
It is also followed by a timestamp (number of seconds since some arbitrary starting date).
Typically there are many seconds between decay events, although it is possible to have more than one in the same second.

For the most part, in my analysis I only use the decay event records.
I did however perform some "sanity checks" on the summary records,
with interesting results described below.

\subsection{Alternatives}
Similar experiments, using different equipment,
are routinely performed at CalTech\cite{CaltechMuon}, UC Berkeley\cite{Berkeley2012}, U Mich\cite{Akerlof2009}, U Minnesota\cite{Hansen2001}, and elsewhere.
Most of these use scintillators far too large for our purposes.
However, the lab notes describe equipment configurations for discrimination, timing and counting
that could be useful.

There are other inexpensive detector options,
including several do-it-yourself ones\cite{CRDetectors},
but I don't analyze them in detail here.
The FermiLab detector\cite{FermiLabDetector} seems the most promising of these,
as it can do muon lifetime experiments and be powered by batteries.

\section{Statistical preliminaries: exponential and geometric distributions}

Before getting into the many sources of experimental noise and error,
it will be worthwhile to analyze the situation where no such problems exist.
For this purpose, we assume that we can measure a decay to infinite precision
and that all events seen are real decays.
We may also assume that the desired effect exists
and can be precisely controlled,
so that we may alter the muon lifetime at will.
Then, we are left with the purely statistical problem
of estimating the muon lifetime from a finite sample of decay events.

Even in the absence of an kind of experimental error,
the inherently random nature of exponential decay introduces a source of variance which cannot be removed.
Given the importance and simplicity of the exponential distribution,
the question of how much data must be sampled has been studied extensively.
Computing this will give us a hard lower bound for the actual experiment, as truncation, binning, noise and error can only increase this number.

Not everything in this section is actually used in the data analysis that follows later.
Topics that aren't are included in the hope that they may prove useful in related experiments.

\subsection{Maximum Likelihood Estimate and its confidence intervals}

The maximum likelihood estimate $\hat{\tau}$ for the lifetime is just the average of all the measured decay times,
\[ \hat{\tau} = \frac{1}{n}\sum_{k=1}^{n}t_k \]
with an exact $100(1-\alpha)\%$ confidence interval given by\cite{wiki_exponential}
\[ \frac{2n\hat{\tau}}{\chi^2_{1-\alpha/2,2n}} < \tau < \frac{2n\hat{\tau}}{\chi^2_{\alpha/2,2n}} \]

Using an online $\chi^2$ calculator\footnote{Using the "Calculate $X^2$ from probability $Q$ and $d$" function at \url{http://www.fourmilab.ch/rpkp/experiments/analysis/chiCalc.html} and iterating on $d$ until it converges to the desired value for $\chi^2$. This algorithm only appears to be numerically stable to about 7 decimal places, so any digits beyond that may not be meaningful.} we get Table 1.

\begin{table}[hbtp]
    \caption{Events $n$ needed to get confidence $(1-\alpha)$ at given $\chi^2$}
    \begin{tabular}{|r|r|r|r|r|r|}
        \hline
        ~                                                  & $\alpha=.02$ & $\alpha=.01$ & $\alpha=.005$ & $\alpha=.002$ & $\alpha=.001$  \\
        \hline
        5.25 MV ($\frac{\chi^2_{\alpha/2,2n}}{2n}=1.050$)  & 3459         & 4446         & 5457          & 6820          & 7866           \\ 
        2.10 MV ($\frac{\chi^2_{\alpha/2,2n}}{2n}=1.020$)  & 21303        & 27353        & 33549         & 41903         & 48316          \\ 
        1.05 MV ($\frac{\chi^2_{\alpha/2,2n}}{2n}=1.010$)  & 84786        & 108825       & 133447        & 166644        & 192125         \\ 
        525 kV ($\frac{\chi^2_{\alpha/2,2n}}{2n}=1.005$)   & 338287       & 434124       & 532287        & 664630        & 766205         \\ 
        210 kV ($\frac{\chi^2_{\alpha/2,2n}}{2n}=1.002$)   & 2111068      & 2708846      & 3321111       & 4146496       & 4779886        \\ 
        105 kV ($\frac{\chi^2_{\alpha/2,2n}}{2n}=1.001$)   & 8439886      & 10829342     & 13276595      & 16575156      & 19105704       \\
        \hline
    \end{tabular}
\end{table}

This table can be read in two ways.
First, it tells us how many data points we need to know the true lifetime to within a certain error with a given level of confidence.
For example, to know the lifetime to within 0.1\% with 98\% confidence, we need 8439886 events (first column, last row).
This is a two-tailed test, as our estimate could be either too high or too low.
For this purpose, we read the $\chi^2$ but ignore the voltage.

We can also use it to determine the number of events needed (assuming the theory is true) to produce a result with any given degree of unlikeliness in the null hypothesis (that there is no effect).
This varies with the voltage of the VDGG, since higher voltages are predicted to produce stronger effects which are easier to distinguish from random noise.
Thus, we can read it as the number of events required, at a given voltage, to produce data making the null hypothesis as unlikely as desired.
(If we pick a single direction, we have a one-tailed test and so the statistical significance level is actually $\alpha/2$.)

%Very roughly, the number of data points required goes down as $1/V^2$ and up as $-\log(\alpha)$ (guessing, need to check).
Given that higher voltages should require many fewer events, it seems desirable to get as large a voltage as practicable, so as to reduce the data requirements.
However, larger VDGGs are more expensive.
Very roughly, the sphere diameter needs to be at least 1 mm per kV (= 1 m per MV),
and the mass (and hence material cost) of the VDGG goes up as at least the cube of this.

\subsection{Sequential Probability Ratio Test}

When one is only trying to distinguish two hypotheses $H_0$ and $H_1$,
and is collecting data slowly over time,
a log-likelihood approach leads directly to the Sequential Probability Ratio Test (SPRT)\footnote{see
Gold \& Shadlen\cite{Gold2007} pages 538-542 for a nice brief exposition, particularly the sidebar on page 541.}
of Signal Detection Theory.
To the $i$th piece of evidence $e_i$ (in this case, a measured decay time) we assign a weight
\[ w_i = \log\frac{P(e_i|H_1)}{P(e_i|H_0)} \]
and our decision variable $y$, the log-likelihood after $n$ samples, is given by the simple sum
\[ y_n = \log\frac{P(e_1,e_2,...,e_n|H_1)}{P(e_1,e_2,...,e_n|H_0)} = \sum_{i=1}^n\log\frac{P(e_i|H_1)}{P(e_i|H_0)} = \sum_{i=1}^nw_i \]
The termination criterion is that we stop and say $H_1$ is true if $y_n \ge \log\frac{1-\alpha}{\alpha}$,
and we stop and say $H_0$ is true if $y_n \le \log\frac{\beta}{1-\beta}$,
and otherwise we continue to collect data.
Here $\alpha$ is the acceptable probability that we falsely conclude $H_1$ is true,
and $\beta$ the acceptable probability that we falsely conclude $H_0$ is true.

For the special case of two exponential distribution hypotheses differing only in their lifetime parameter,
($\frac{1}{\tau_0}e^{-t/\tau_0}$ versus $\frac{1}{\tau_1}e^{-t/\tau_1}$),
we have that
\[ P(e_i|H_0) = \frac{1}{\tau_0}e^{-t_i/\tau_0} \]
\[ P(e_i|H_1) = \frac{1}{\tau_1}e^{-t_i/\tau_1} \]
\[ w_i = w(t_i) = \log\frac{P(e_i|H_1)}{P(e_i|H_0)} = \log(\frac{1}{\tau_1}e^{-t_i/\tau_1}) - \log(\frac{1}{\tau_0}e^{-t_i/\tau_0}) \]
\[ = \frac{-t_i}{\tau_1} - \log(\tau_1) - \frac{-t_i}{\tau_0} + \log(\tau_0) \]
\[ = \left(\log(\tau_0) - \log(\tau_1)\right) + t_i(\frac{1}{\tau_0} - \frac{1}{\tau_1}) \]
%\begin{align*}
%& w_i = w(t_i) = \log\frac{P(e_i|H_1)}{P(e_i|H_0)} = \log(\frac{1}{\tau_1}e^{-t_i/\tau_1}) - \log(\frac{1}{\tau_0}e^{-t_i/\tau_0}) \\
%& = \frac{-t_i}{\tau_1} - \log(\tau_1) - \frac{-t_i}{\tau_0} + \log(\tau_0) \\
%& = \left(\log(\tau_0) - \log(\tau_1)\right) + t_i(\frac{1}{\tau_0} - \frac{1}{\tau_1})
%\end{align*}
The expected weight if $H_1$ is true would then be
\[ \langle w|H_1 \rangle = \int_0^{\infty} P(t)w(t)dt \]
\[ = \int_0^{\infty} \frac{1}{\tau_1}e^{-t_i/\tau_1} \left( \left(\log(\tau_0) - \log(\tau_1)\right) + t_i(\frac{1}{\tau_0} - \frac{1}{\tau_1}) \right) \]
\[ = \left(\log(\tau_0) - \log(\tau_1)\right)\int_0^{\infty} \frac{1}{\tau_1}e^{-t/\tau_1} dt + (\frac{1}{\tau_0} - \frac{1}{\tau_1}) \int_0^{\infty} \frac{1}{\tau_1} t e^{-t/\tau_1} dt \]
But the first integral is just 1 and the second integral just gives the expected value of $t$ over the entire distribution, which we know is $\tau_1$, so
\[ \langle w|H_1 \rangle =  \left(\log(\tau_0) - \log(\tau_1)\right) + (\frac{\tau_1}{\tau_0} - 1) \]

If we are able to change the muon lifetime by a fraction $\delta$, so that $\tau_1 = (1+\delta)\tau_0$, then
\[ \langle w|H_1 \rangle =  \left(\log(\tau_0) - \log((1+\delta)\tau_0)\right) + (\frac{(1+\delta)\tau_0}{\tau_0} - 1) = \delta - \log(1+\delta) \]
For $\delta=0.01$, which is what we would predict for a voltage of 1.05MV, we get
\[ \langle w|H_{1.01\tau_0} \rangle = 0.01 - 0.009950331 = 0.000049669 \]
This can be used to directly calculate the expected number of events needed to achieve any given likelihood ratio.
For example, if we want $H_1$ to be 1000 times more likely than $H_0$, we need about
\[ \frac{\log(1000)}{\langle w|H_1 \rangle} = \frac{6.907755}{0.000049669} = 139075 \pm 373 \]
decay events, where $373 \approx \sqrt{139075}$ is an estimate of the standard deviation of this number.
This is roughly comparable to the estimate 166644 given in the $\chi^2=1.01, \alpha=.002$ entry of Table 1.

\subsection{Fisher Information analysis}

We can also analyze this in terms of Fisher Information.
FI is mostly useful through the Cramer-Rao inequality
\[ (\Delta \tau)^2 \ge \frac{1}{I(\tau)} \]
in which the inverse of the Fisher Information gives a lower bound on the variance of our estimate of the lifetime $\tau$.

The FI for our purposes measures the amount of information that a single decay time $t$ carries about the unknown lifetime parameter $\tau$ upon which the probability of $t$ depends.
It is defined as the expectation of the square of the partial derivative with respect to the parameter of the log-likelihood function.
\[ I(\tau) \equiv E\left[ \left( \frac{\partial}{\partial\tau} \log f(t;\tau) \right)^2 \bigg| \tau \right] = E\left[ \left( \frac{\partial}{\partial\tau} \log \left(\frac{1}{\tau}e^{-t/\tau}\right) \right)^2 \bigg| \tau \right] \]
\[ = E\left[ \left( \frac{\partial}{\partial\tau} \left(\frac{-t}{\tau} -\log(\tau)\right) \right)^2 \bigg| \tau \right] = E\left[ \left( \frac{t}{\tau^2} - \frac{1}{\tau} \right)^2 | \tau \right] = \frac{1}{\tau^4} E\left[ (t-\tau)^2 \big| \tau \right] \]
But this last expectation is just the variance of $t$, which is $\tau^2$, so the FI for a single decay event is
\[ I(\tau) = \frac{1}{\tau^2} \]
and for $n$ decay events is just
\[ I(\tau) = \frac{n}{\tau^2} \]
so that 
\[ (\Delta \tau)^2 \ge \frac{1}{I(\tau)} = \frac{\tau^2}{n} \]
or
\[ \frac{\Delta \tau}{\tau} \ge \frac{1}{\sqrt{n}} \]
If we assume approximately Gaussian error in $\tau$ for $n$ large,
we can use this to estimate the minimum number of events required
to know $tau$ with a standard deviation $\sigma \equiv \Delta\tau < \alpha\tau$ as
\[ n \ge \frac{1}{\alpha^2} \]
From this we can see that $\alpha=.001$ gives $n \ge 1000000$.
This is not exactly comparable to the numbers calculated above,
since for $H_1$ and $H_0$ differing by 1\% it would separate the two hypotheses by 10$\sigma$.

If we apply this to the latest MuLan muon lifetime number $2.197019\pm0.000021$ $\mu$S\cite{MuLan2007},
we get $n \ge 10945334436$,
implying that it should have taken a {\em minimum} of about 11 billion muon decay events to achieve this accuracy,
even in the complete absence of any experimental error.

%\section{Exponential distribution with uniform noise}

%(NOTE THIS SECTION IS NOT RIGHT YET!)

%Now that we fully understand the behavior of a pure exponential distribution,
%and before we start considering the many sources of experimental error,
%let's briefly look at the pure exponential with a pure uniform noise source added.
%The key observation here is that,
%if we are only concerned with the {\em first} event,
%then the time to that event for a uniform distribution is in fact exponentially distributed!
%Thus (if we ignore all following events)
%we can characterize the rate parameter $\nu$ of the noise (in events per second)
%and the rate parameter $\lambda = 1/\tau$ of the decay,
%and simply add them to get the total rate.
%For $N$ starting particles, this gives us a density of events at time $t$ of
%\[ f(t;\tau,N,\nu) = Nf(t;\tau) + \nu = \frac{N}{\tau} e^{-t/\tau} + \nu \]
%Note that this is {\em not} a probability distribution, since the $\nu$ part is not normalizable.
%However if we truncate this to any finite window,
%it becomes a perfectly fine distribution and easy to normalize.

%\subsection{Fisher Information analysis}

%Here it easier to use the chain rule form of Fisher Information by noting that
%\[ \frac{\partial}{\partial\tau}\log f(t;\tau,N,\nu) = \frac{\frac{\partial}{\partial\tau} f(t;\tau,N,\nu)}{f(t;\tau,N,\nu)} 
%= \frac{N \frac{\partial}{\partial\tau} f(t;\tau,1,0)}{f(t;\tau,N,\nu)} \]
%since $\partial\nu / \partial\tau = 0$ and $N$ can be pulled outside the derivative.
%This is similar to the formula {\em without} noise,
%except for the $\nu$ term in the denominator.
%Thus the noise acts to dilute or reduce the information obtained, in a ratio of
%\[ \frac{I(\tau,N,\nu)}{I(\tau,N,0)} = \frac{f(t;\tau,N,0)}{f(t;\tau,N,\nu)} \]

%This gives us
%\[ I(\tau;N,\nu)  = E\left[ \left( \frac{N\frac{\partial}{\partial\tau} \left(\frac{1}{\tau} e^{-t/\tau} \right)}{\frac{N}{\tau} e^{-t/\tau} + \nu} \right)^2 \bigg| \tau \right] \]
%\[ = E\left[ \left( \frac{\frac{\partial}{\partial\tau} \left(\frac{1}{\tau} e^{-t/\tau} + \nu \right)}{\frac{N}{\tau} e^{-t/\tau} + \nu} \right)^2 \bigg| \tau \right]
%  = \frac{1}{\tau^4} E\left[ (t-\tau)^2 \big| \tau \right] \]
%%But this last expectation is just the variance of $t$, which is $\tau^2$, so the FI for a single decay event is
%%\[ I(\tau) = \frac{1}{\tau^2} \]
%%and for $n$ decay events is just
%%\[ I(\tau) = \frac{n}{\tau^2} \]
%%so that 
%%\[ (\Delta \tau)^2 \ge \frac{1}{I(\tau)} = \frac{\tau^2}{n} \]
%%or
%%\[ \frac{\Delta \tau}{\tau} \ge \frac{1}{\sqrt{n}} \]

%\section{Sources of error in the estimation of muon lifetime}

%\subsection{Randomness of decay}

%However, even an inexpensive educational VDGG can reach 500 kV, so that we are unlikely to have to go below the fourth row.
%Achieving .001 significance even at that level only requires about 766K events.

%We also know that "sequential sampling from an exponential population is essentially equivalent to observing a Poisson process"\cite{Sayyad1969}
%and that the variance of a Poisson process with parameter $\lambda$ is itself $\lambda$.
%(Note that $\lambda = 1/\tau$, where $\tau$ is the $1/e$ lifetime.)
%That is, for any given $\lambda$, the number of decays seen in each bin is Poisson-distributed.

%Assuming we are measuring a muon lifetime $\tau$ that has been altered by 1\%, and wish to distinguish it from the unaltered one $\tau_0$ at a significance level $\alpha$,
%we need the relative likelihood of the experimental evidence under the default hypothesis $H_{\tau_0}$ versus the time-altered hypothesis $H_\tau$ to be less than $\alpha$.
%There are several ways to approach estimating how much data this requires.

\subsection{Truncation of distribution}

It is traditional to truncate the exponential distribution on the right;
the Teachspin software does this by default at no more than 20 $\mu$S (about 9 lifetimes).
This is done both because we cannot wait forever for any single muon to decay,
and because after some time any "decay" event seen is much more likely to be noise than an actual decay.
However, it is rare that this truncation is treated exactly.

In this subsection we continue to ignore the noise issue,
but focus entirely on the problem of estimating the true distribution mean from a truncated sampling procedure.
This problem has been solved analytically by Al-Athari\cite{Al-Athari2008};
most of what follows is adapted from his paper.

Let the length of the sampling interval be $b$.
If our complete distribution is
\[ \frac{1}{\tau} e^{-t/\tau} \]
with mean $\tau$, the truncated distribution has mean
\[ \tau' = \tau - \frac{b}{e^{b/\tau} - 1} \]
where the second term essentially subtracts off the mean of the truncated portion,
weighted by the probability that a sample from the full distribution would be truncated.

Especially for large sample size $n$, we would expect the sample mean $\bar{t}$ to be less than $b/2$,
but there is some probability that this will not be true.
If it isn't, then no maximum likelihood estimator exists.
However, the chance of this occurring rapidly approaches 0 as $n\rightarrow\infty$.

The likelihood function is
\[ \frac{e^{-n\bar{t}/\tau}}{\tau^n(1-e^{-b/\tau})^n} \]
Maximizing this (or more usually its log) gives the MLE $\hat{\tau}$ for $\tau$.
(Al-Athari actually finds the MLE for $\theta = 1/\tau$,
but since he uses the log-likelihood,
the inversion becomes just a sign change and the MLE is the same either way.)
If $\bar{t} < b/2$ we are guaranteed that the MLE exists,
i.e. that the derivative of this is zero at some finite value.
(If $\bar{t} \ge b/2$, the MLE doesn't exist, but we can use $b/2$ as our estimate.
This is Al-Athari's Modified MLE (MMLE), and is equivalent to assuming a uniform distribution,
which is the limit of the exponential distribution as the lifetime goes infinite.)

Thus (skipping a few steps) we want to solve
\[ n ( \hat{\tau}' - \bar{t} ) = 0 \]
i.e. find the $\hat{\tau}'$ that correctly predicts the sample mean.
(In the full exponential case this is simply $\hat{\tau} = \bar{t}$.)
Since we know $n$ is not zero, we get $\hat{\tau}' = \bar{t}$.

Al-Athari stops here, but that doesn't give us a closed-form solution for $\hat{\tau}$ as a function of $b$ and $\bar{t}$.
Substituting back in, we get
\[ \hat{\tau}' = \hat{\tau} - \frac{b}{e^{b/\hat{\tau}} - 1} = \bar{t} \]
which can be solved numerically for $\hat{\tau}$ given $\bar{t}$ and $b$.
%\[ \hat{\tau} - \bar{t} = \frac{b}{e^{b/\hat{\tau}} - 1} \]
%\[ (e^{b/\hat{\tau}} - 1)(\hat{\tau} - \bar{t}) = b \]
%\[ e^{b/\hat{\tau}}\hat{\tau} - e^{b/\hat{\tau}}\bar{t} - \hat{\tau} + \bar{t} = b \]

\subsection{Binning and the geometric distribution}

The Teachspin timing FPGA operates on a 50 MHz (20 nS) clock $\pm$100 ppm.
Ignoring clock error for the moment,
what is the effect of putting decays into finite-width bins?

\subsubsection{Geometric distribution}

Binning converts the exponential distribution into a geometric distribution.
%(This is the only discrete distribution which is memoryless.)
If we number the bins starting at 0, the probability that a single muon will decay in bin $k$ is
\[ P(K=k) = (1-p)^kp \]
where $p$ is the probability that a muon will decay in 1 bin time if it has not decayed already.
For a given lifetime $\tau$ and bin width $b$, we have
\[ p = p(\tau,b) = \int_{t=0}^b \frac{1}{\tau}e^{-t/\tau} dt = -e^{-t/\tau}\bigg|_0^b = 1 - e^{-b/\tau} \]
For $\tau = 2031.79$ nS (our experimental result below), and $b = 20$ nS, this gives $p = 0.0097574$,
so for each bin there is about a 1\% chance that a muon will decay, and a 99\% chance it will survive.
The expected value is just
\[ \langle K \rangle = \frac{1}{p} \]
and the MLE for $p$ just the inverse of the sample mean
\[ \hat{p} = \frac{1}{\bar{K}} \]

Truncation of the geometric distribution has similar effects to truncation of the exponential distribution.
The probability that a muon which decays in one of the first $B$ bins will decay in bin $k$ is
\[ P(K=k) = \frac{(1-p)^kp}{1 - (1-p)^B} \]
which renormalizes the truncated distribution to have total probability 1.

\subsubsection{Bin offset}

The decays within a bin could of course have happened at any time during the bin window.
For very small bins, we expect that the average decay time within a bin will be slightly less than
the bin start time plus half the bin width,
since the exponential distribution is monotonic decreasing.
We can quantify this precisely using the truncated exponential analysis given above.
Let $\tau'(\tau,b)$ be the expected value of the decay time in a bin of width $b$.  Then
\[ \tau'(\tau,b) = \tau - \frac{b}{e^{b/\tau} - 1} \]
as before, except that we now expect $b/\tau$ to be fairly small.
For $\tau = 2031.79$ nS and $b = 20$ nS, this gives $\tau' = 9.9836$ nS,
which is (as expected) slightly less than 10 nS.
Thus, for an unbiased estimate with that $\tau$ and $b$, we should treat all the decays in the $k$th bin
(which spans 20$k$ to 20$(k+1)$ nS)
as if they decayed at 20$k$ + 9.9836 nS.

Failing to do this and instead using 10 nS would give a positive bias to our estimated $\tau$ of about 0.0164 nS,
or about +8 ppm.
This is small relative to the clock uncertainty of $\pm$100 ppm.

\subsection{Exponential and geometric decay are memoryless}

We note here in closing that a property unique to the exponential and geometric distributions is that they are {\em memoryless};
the probability of an event occurring does not depend on how long we have already waited for it to occur.
Another way of saying this is that they have a constant failure rate.
Because muon decay (like nuclear decay) follows an exponential decay pattern,
we do not need to be concerned with the history of the muon before it arrives in our apparatus.
Indeed, the entire experiment would not be possible without this property,
since we do not measure the {\em entire} lifetime of the muon from its creation in a pion decay while still traveling at nearly lightspeed,
but only its lifetime after coming to rest in our detector.

\section{Sources of Experimental Error}

Here are all the sources of error I can think of in the Teachspin experiment,
along with analyses of their effects and any ways of eliminating or compensating for them.

\subsection{Offset between stopping and decaying pulses}
The light in a stopping pulse is generated BEFORE the muon stops, while it is still moving.
The light in a decay pulse is generated AFTER the muon decays, mostly by the emitted electron.
Since the pulse detector works on the leading edge of both, that means it starts counting the stopping pulse too soon.
If the muon is still moving, there may be some SR time dilation that would lengthen its lifetime.

NET EFFECT: Should make measured lifetimes longer than actual ones.
Rough order of magnitude would be the width of the stopping pulse.
For my setup, the analog pulses were about 25-35 nS wide at the base, and about 4-20 nS wide at trigger level,
based on visual inspection of about a hundred pulses on a digital storage scope.
Thus we estimate a systematic bias of about $(4 + 20)/2 = 12$ nS and a $\sigma$ of no more than 8 nS for this ($\sigma^2 = 64$ nS$^2$).

SOLUTION: Discarding initial bins (see below) makes this problem go away for the stopping pulse.
For the decay pulse, we get a triggering offset of about 9 nS (from start of pulse to time of trigger) $\pm$8 nS.
We also have to add another 5.5$\pm$1.5 nS offset from the analog pulse to the digital pulse.
This gives us a total triggering correction and error of $\delta_{trig} = -14.5 \pm 9.5$ nS.

\subsection{Error due to variability in pulse size/shape}
% (2a stopping pulse, 2b decay pulse)
Since the discriminator circuit is tuned to a specific voltage level, and the leading edge has finite slope, and the size of the pulse may vary, we would expect a larger pulse to trigger slightly sooner than a smaller pulse.

NET EFFECT: Random errors in the time that the pulse is detected.
Min to max range would be somewhat less than half the typical pulse width
(soonest would be the point where the largest pulse triggers, latest would be near the middle (top) of a small pulse just barely able to trigger).
Based on the observations above, we estimate this to contribute $\sigma_p=4$ nS ($\sigma_p^2 = 16$ nS$^2$) for each pulse.

SOLUTION: Discarding initial bins removes this problem for the stopping pulse, but not for the decay pulse.

\subsection{Metastability of discriminator}
% (3a stopping pulse, 3b decay pulse)
Any time a circuit has to take an analog input and make a digital decision on it, there will be signals very close to the decision threshold that can cause the circuit to hang in a metastable intermediate state.  (This problem occurs most famously with flip-flops receiving data asynchronously to their clocks, but it can be caused by thresholds in voltage as well as in time.)  There is no theoretical upper bound to how long this hanging can occur; however, the probability of continued hanging decays exponentially with time (it is an unstable equilibrium like a pencil balancing on its point).  The exact behavior depends on circuit construction; a good circuit can make this problem very unlikely, at the cost of taking more time to make the decision.  I don't know yet what the details of the Teachspin discriminator are.

NET EFFECT: Until analyzed more closely,
we should assume that there may be occasional pulses which are effectively delayed by an entire clock cycle, or even (much more rarely) two.
Since this can happen on either pulse, it could lengthen or shrink the measured decay time.
Large and small pulses may behave differently;
if there is a difference in pulse sizes between stopping and decay pulses, we could get a net average offset, but if not the mean of this should be zero.
Although the magnitude of such an error would be on the order of $\pm10$ nS,
metastability events are very rare (1 in millions or billions), so the estimated $\sigma_{ms}$ here would be 0.1 nS or less.

\subsection{Digitization error of pulse time}
% (4a stopping pulse, 4b decay pulse)
I assume that the pulses are digitized to synchronize with a clock pulse that has 20 nS (the bin size) cycle time since the file data is reported in multiples of 20 nS.

NET EFFECT: This adds a random error which is roughly uniformly distributed over the 20 nS cycle time,
giving a systematic offset of approximately half the cycle time or 10 nS,
and adding a variance of approximately $\sigma_{dig}^2 = \frac{1}{12}(20\ nS)^2$ \cite{wikiUniform}
to a single event time.
If both stopping and decay pulses contribute this, the offsets cancel but the variances add.
For $n$ events, this variance scales linearly, so the standard deviation of the average scales as $1/\sqrt{n}$.

SOLUTION: Discarding initial bins removes this problem for the stopping pulse, but not for the decay pulse.
For either pulse, to zeroth order we can treat all decays in a bin as occurring at the center of the bin (+10 nS).
As noted earlier, a more exact correction can be computed if we know the decay time.
Since we use this number to compute the estimated decay time,
we would appear to be using circular reasoning;
however, since the effect of the decay time on the offset is small,
and the effect of the offset on the decay time is small,
in practice we can ``go around the circle'' a few times and get excellent convergence.
%IMPLEMENTATION: I currently use the zeroth order correction only (all decays are assumed to be at the center of their bin, i.e. 10 nS after the bin start for 20 nS bins).
%I plan to change this to the more exact number

IMPLEMENTATION:
Using the bin offset formula above plus the uniform approximation for variance, we take $\delta_{dig} = (\tau - \frac{b}{e^{b/\tau} - 1}) \pm \frac{10}{\sqrt{3n}}\ {\rm nS}$.
%However, bin offset is not needed when fitting to a geometric distribution.

\subsection{Inability to detect very fast decays}
Very fast decays may be difficult or impossible to detect.
Since the scintillator takes nanoseconds to emit all its light,
two pulses starting less than a few nanoseconds apart may appear to be one wide pulse.
There may also be issues throughout the analog circuitry, from the PMT to the discriminator;
each may require some time after emitting a pulse to recover and be ready for another one.
The recording computer, USB interface, and software may also impose limits.
Examination of a large output file with over 100K decay events shows zero decays in the 0 nS and 20 nS bins,
and a reduced number of decays in the 40 nS bin.
This implies that all decays shorter than about 40-50 nS are being lost.

NET EFFECT: Decays faster than some minimum time are lost.
Fitting to this data will give wrong answers.

SOLUTION: Fortunately, exponential decay is memoryless.  We can simply discard the first few bins to solve this problem.
Doing so also fixes many of the above problems.
It also has the effect of synchronizing all the muon decay start times with the beginning of the first undiscarded bin.

IMPLEMENTATION: My analysis software currently discards the first 3 bins (all decays marked as 40 nS or less).
This loses about 0.1\% of the data, which is acceptable.

\subsection{Clock jitter and drift}
The clock driving the bin sampling is not perfect, but will have some jitter.
It may also drift slightly over time due to temperature, circuit aging, power supply variation, or other causes.
For any reasonably good crystal oscillator, this will probably be much smaller than some other sources of error listed here and so negligible, but it is not zero.
Teachspin claims its clock is accurate to $\pm$100 ppm.
This could be measured by a device with a more accurate clock,
but for this report we simply assume that the clock period may both have a fixed offset of $\pm 2$ pS (100 ppm of 20 nS)
and a uniformly-distributed random jitter of the same magnitude, contributing $\frac{1}{12}(4\ {\rm pS})^2$ variance to individual decay times.
This jitter is so much smaller than the digitization error above that we ignore it.

NET EFFECT: We are left with a $\delta_{clock} = \pm10^{-4}\tau$ from our uncertainty about the actual clock period.

\subsection{False decay noise due to separate transit events close together}
This is probably the largest and most serious noise problem in the experiment.

NET EFFECT: If we assume that the transits are random, then the first transit has a uniform probability over time and the second one has the same distribution, so the probability of a false decay event from two transits is proportional to the decay window size times the square of the transit probability.

SOLUTIONS: Given the power of 2, the easiest way to reduce this noise would be to reduce transit events.  Cutting them down by a factor of 10 would reduce the false decay from this cause by a factor of 100.  One approach of course is to use a muon beam with momentum tuned to mostly stop in the detector, i.e., to increase the number of true decay events relative to the false ones.  Staying with cosmogenic muons only, detector paddles above and below the main scintillator could give signals that would allow us to detect and filter out many transit events.

It is also possible to estimate the mean number of false decays per bin and to "subtract that out" of the data in various ways.  However, this still leaves residual errors from (a) the error in estimating the mean, and (b) the variation about the mean.  An alternate statistical approach would be to leave in all the decay events (true and false), but estimate the probability that each one is true (which will depend on the bin) and weight them accordingly.  This is particularly simple in the Bayesian approach, where the log (relative) probability of the (true) event is simply added to the log (relative) likelihood of the hypothesis: we can just multiply that log event probability by the probability that the event is true and add that instead.

IMPLEMENTATION: We fit a model which has noise level as a parameter.
Both errors in fitting the average noise level, and variance from the noise, should contribute error to our lifetime estimate,
but quantifying these errors is not trivial.
It can be estimated from Monte Carlo simulation, but we haven't done that.
 
\subsection{Correlated noise}

In the previous subsection we assumed that the background noise is independent,
i.e.\ that the probability of a transit event is not correlated with other transit events.
There could be cases where this is not true.
For example, a highly energetic cosmic ray hitting part of the building structure
could generate a shower of secondary particles
and thus cause a cluster of transit events.

Since these particles would mostly still be traveling at close to lightspeed,
and light travels about a foot per nanosecond,
the time skew between two particles (in nS)
would be roughly the length difference of their paths to the detector (in feet).
We expect that most of these clusters of events would spread only a few nS,
and thus are being filtered out both by the inability of the device to measure short delays
and by our discarding of the first three 20 nS bins.
Thus, only skews of greater than 60 nS (implying either a delta-path-length of over 60 feet,
or one particle moving much slower than lightspeed)
would be able to cause false decay events.
These seem sufficiently unlikely that we can ignore them.

\subsection{Transit Time Spread in PMT}

"The delay between the absorption of a photon at the photocathode and the output pulse from the anode of a PMT
varies from photon to photon.
The effect is called 'transit time spread' or TTS.
There are three major TTS components in conventional PMTs and MCP PMTs - the emission at the photocathode, the multiplication process in the dynode system or microchannel plate, and the timing jitter of the subsequent electronics."\cite{Becker2003}

NET EFFECT:
Even in fairly slow PMTs. the TTS is rarely greater than 100 pS.
This is small relative to some of the other sources of error we have considered, but we include a $\sigma_{tts}=\pm0.1$ nS for completeness.

\subsection{Afterpulsing}

"Most detectors have an increased probability to produce a dark count pulse in a time interval of some 100 nS to some $\mu$S after the detection of a photon."\cite{Becker2003}
If we were doing single-photon detection,
this would be interpreted as a (false) decay event if it occurred within the decay window.
In this sense, afterpulsing is similar to background noise from transit events.
However, the background noise is uncorrelated, while afterpulsing is highly correlated.
Also, since we are looking for a large burst of photons rather than single photons,
a single-photon-sized event would not normally trigger the pulse detector
(our detector threshold (about 14 mV) was set well above the dark noise level of the PMT (about 1 mV)).

NET EFFECT: We expect afterpulsing to at worst slightly raise the dark noise level,
and thus not be a serious source of false decay events by itself.
However, it might slightly alter the pulse height threshold for decays at the afterpulse time.
This could have the effect of slightly increasing the number of decay events seen around the afterpulse time,
and hence slightly biasing the decay lifetime collection.

Since we have so far no details about the afterpulse behavior of the specific PMT used,
it is difficult to estimate the magnitude of any such error.

\subsection{Binomial sampling noise of $\mu^+ / \mu^-$ mixture}
All of the above would apply even if all the muons were a single type.
However, cosmogenic muons are are a mixture of muons ($\mu^-$) and antimuons ($\mu^+$)
with a slight excess of antimuons.
Values for the ratio of $\mu^+/\mu^-$ (the "charge ratio" $r$) in the literature vary from 1.08 to 1.3.

The CPT Theorem plus the assumption of EM-gauge invariance (as in the Standard Model)
would require that these have identical masses and lifetimes in vacuum,
but in matter their lifetimes differ because $\mu^-$ have an additional decay mode
of being captured by an atomic nucleus.
The best current lifetime numbers are $\tau_+ = 2197.019\pm0.021$ nS\cite{MuLan2007} for $\mu^+$ in vacuum
and $\tau_- = 2043\pm3$ nS for $\mu^-$ in carbon.

The lifetime measured in the Teachspin device is a weighted average of these two numbers,
with the weights given by the actual numbers of $\mu^+$ and $\mu^-$ detected.
However, we don't know these actual numbers, and they will vary from data set to data set.
So the expected mix of muons and antimuons will have a binomial distribution

\[ f(n_+;n,p) = \binom{n}{n_+} p^{n_+}(1-p)^{n_-} \]

where $n$ is the total number of muons,
$p = r/(r+1)$ is the {\em a priori} probability that a detected muon will be a $\mu^+$,
$n_+$ is the actual number of $\mu^+$ in our sample,
$n_- = n - n_+$ is the number of $\mu^-$.
This has mean
\[ \langle n_+ \rangle = np \]
and variance
\[ \sigma^2(n_+) = np(1-p) \]

The variance is highest when $p=1/2$, or $r=1$.
Thus we will have a higher variance if $r=1.08$ than if $r=1.3$.
For $r=1.08$ we get $p=0.519$, $\langle n_+ \rangle = 0.519n$, and $\sigma^2(n_+) = 0.2496n$.
For $r=1.3$ we get $p=0.565$, $\langle n_+ \rangle = 0.565n$, and $\sigma^2(n_+) = 0.2457n$.

NET EFFECT: Fortunately, the uncertainty in $r$ doesn't affect our $\tau$ calculations as long as we assume that $r$ is constant over time.
%The net result is that we have two additional sources of variance in our $\tau$ estimate.
We don't know the exact ratio of $\mu^+$ to $\mu^-$, since estimates in the literature vary
and may depend on altitude, latitude, and other factors.
This adds about $\pm\frac{1}{2}(0.565-0.519)(\tau_+ - \tau_-) = \pm(0.046)(154\ {\rm nS}) = \pm7.08$ nS
uncertainty to what our effective (mixed) $\tau$ should actually be in theory,
but it doesn't affect how we measure the effective $\tau$.

Still, we have the binomial sampling variance of up to $0.2496n(\tau_+ - \tau_-)^2 = 5919.51n\ {\rm nS}^2$.
(Note that this is very close to the theoretical maximum.
Even at $p=1/2$, we would see exactly 0.25 instead of 0.2496.)
This is the variance contribution for the sum of all decay times;
normalizing this down to a single average decay time gives us
\[ \sigma^2_{binom} = \frac{5919.51}{n} {\rm nS}^2 \]
\[ \sigma_{binom} = \frac{76.94}{\sqrt{n}} {\rm nS} \]
For our larger data sets, with $n$ from approximately 2330 to 20161,
this gives $\sigma_{binom} = 1.59$ nS to $\sigma_{binom} = 0.54$ nS.

\section{Analysis of actual Teachspin data}

In this section we analyze actual Teachspin data to evaluate the real-world performance of the methods developed earlier.

\subsection{The data sets}
25 pre-existing data sets were available from students in the spring 2012 Advanced Physics Lab course at CSU.
These are shown in Table 2 as A through Y.
Some of these were very short and recorded zero decay events.
Equipment settings are not recorded in the data files and were impossible to reconstruct.
I also collected 3 large data sets of my own between Sept 7th and Oct 15th, shown as Z$_1$ through Z$_3$.
For these, the threshold dial was set to 3.5, resulting in a trigger voltage of about 14 mV at the pulse detector.
\begin{table}[hbtp]
    \caption{Muon lifetime data sets}
    \begin{tabular}{|c|c|r|r|r|r|r|}
        \hline
        ~ & Date \&  Time          & Seconds & Length & Missing & Decays & Transits \\ \hline
%        2009/11/28 16:20 & 1501   & 1514      & 13        & 0            & 0              \\ 
%        2009/11/28 19:13 & 9          & 9             & 0          & 0            & 0              \\  \hline
        A & 2012/01/31 14:32 & 61          & 61            & 0           & 0            & 428              \\ 
        B & 2012/01/31 14:34 & 12          & 39            & 27         & 0            & 59              \\ 
        C & 2012/01/31 14:46 & 10062   & 166615  & 156553 & 85         & 45678            \\ 
        D & 2012/02/02 13:05 & 431255 & 431916  & 661       & 9009   & 3174760             \\ 
        E & 2012/02/14 14:01& 3238      & 3271       & 33         & 3196     & 24259    \\
        F & 2012/02/16 13:08 & 3537     & 3543       & 6            & 89         & 26983    \\
        G & 2012/02/16 14:10 & 11          & 11           & 0            & 0           & 46             \\
        H & 2012/02/23 13:44 & 1032730 & 1034759 & 2029 & 21757 & 7718681 \\
        I & 2012/03/06 13:36 & 331          & 332       & 1           & 7           & 2074 \\
        J & 2012/03/06 13:42 & 592          & 593        & 1           & 5             & 1805 \\
        K & 2012/03/06 13:52 & 348         & 348          & 0          & 1           & 2391 \\
        L & 2012/03/06 13:58 & 1384     & 1386        & 2           & 24         & 9448 \\
        M & 2012/03/06 14:21 & 646320 & 647669  & 1349    & 13902   & 3655672 \\
        N & 2012/03/22 14:08 & 127        & 128         & 1           & 4             & 913     \\
        O & 2012/03/22 14:11 & 7              & 7             & 0           & 0            & 42   \\
        P & 2012/03/22 14:15 & 4358      & 4367       & 9           & 20034   & 213503 \\
        Q & 2012/04/05 15:35 & 473249 & 474128 & 879       & 0           & 810 \\
        R & 2012/04/19 13:22 & 9191    & 9570      & 379       & 89          & 44903  \\
        S & 2012/04/24 14:41 & 167083 & 167379 & 296      & 2586     & 1155656 \\
        T & 2012/04/26 13:21 & 4765    & 4772       & 7           & 81          & 22537 \\
        U & 2012/04/26 15:00 & 5419   & 5427      & 8            & 86         & 28342 \\
        V & 2012/05/01 15:32 & 1469   & 1471       & 2            & 21         & 7473 \\
        W & 2012/05/03 13:14 & 5           & 5             & 0            & 0            & 18 \\
        X & 2012/05/03 13:17 & 9583    & 9598      & 15          & 178       & 68048 \\
        Y & 2012/05/03 15:57 & 430651 & 431341 & 690      & 7128    & 2981465 \\  \hline
%        Z0 & 2012/08/27 13:09 & 159        & 160        & 1           & 2           & 986 \\
%        MD & 2012/08/27 13:12 & 784008 & 11404444 & 10620436 & 13111 & 5446296 \\
        Z$_1$ & 2012/09/07 12:05 & 485774 & 486625 & 851      & 6726    & 2939733 \\
        Z$_2$ & 2012/09/14 11:32 & 736361 & 737832 & 1471    & 10454 & 4463818 \\
        Z$_3$ & 2012/09/28 12:04 & 1466550 & 1468753 & 2203    & 21502 & 8939629 \\
        \hline
    \end{tabular}
\end{table}

\subsection{Missing time\-stamps}
Some internal inconsistencies were noted in the files,
particularly missing time\-stamps.
One line is supposed to be written every second recording the number of transit events seen in that second;
the last field in the line is a timestamp in seconds.
The timestamps should be consecutive,
and the number of them (shown in the table as "Seconds")
should equal the last time stamp minus the first timestamp plus one (shown as "Length").
The difference "Missing" (= Length - Seconds) gives the number of missing timestamps.

Most of the time, only a small fraction of the data (less than 2\%) is missing.
This kind of effect might happen if the counter clock were slower than the PC clock,
and the timestamps were generated by the PC.
In that case we would expect the fraction of missing seconds to be consistent across all data sets,
because it would be roughly equal to $1 - \frac{PCClockPeriod}{CounterClockPeriod}$.
However, this is not what we see in the given data sets.
The fraction missing, and their locations in the files, seem more random than that.

This could perhaps be explained by occasional software glitches dropping a data packet,
possibly caused by the PC software sometimes not getting enough CPU time and a failure to implement a reliable communications protocol with adequate hardware buffering and handshaking.
However, in data set C more than 90\% of the data is missing,
which cannot easily be explained in this way.
Most of the missing data in C comes from a single gap in timestamps between 1328055282 and 1328210272,
accounting for 154991 of the 156553.
However, there are still many individual single missing timestamps.
Thus it seems likely that there are at least 2 or 3 different causes of data dropout problems.
Debugging these problems would be time-consuming and is beyond the scope of the present report.

This discrepancy complicates the data analysis,
especially as regards the average number of transit events per second,
which is one important way of estimating the background noise.
It is probably fairest to divide Transits by Seconds to estimate this,
since any transit events in the lost seconds would not have been counted.

\subsection{Gradient descent: Design}

In a Machine Learning approach,
we could simply treat the data as being modeled by 3 parameters:
the decay lifetime $\tau$, the initial number of decaying muons $N$,
and the background noise level $\nu$.
A minimum-variance fit to the data would give us estimates of all 3 parameters.

A more detailed procedure is as follows:
%We first give a rough estimate of the background noise level $\nu$
%as just the total number of transit events, divided by the total number of seconds,
%times the bin width $b = 20$ nS in seconds (.00000002).
We estimate the initial decay lifetime $\tau$,
% as 2.2 $\mu$S,
the initial population $N$,
% as the total number of decay events,
and the initial background noise $\nu$.
% as 0 (no noise).
The hypothesis for each bin $k$ is then
\[ H(N,\tau,\nu,k) =  N(1-p)^k p + \nu \]
 where $p = p(\tau) = 1 - e^{-b/\tau}$ as above, and $\nu$ is the expected number of false decay events in a single bin.
We want to find the $N,\tau,\nu$ that minimizes the error or variance
\[ V = \sum_{k=0}^{B-1} (H(N,\tau,\nu,k) - Y(k))^2 \]
where $Y(k)$ is the actual data for bin $k$ and $B$ is the number of bins.

Since this is nonlinear in $p$ and $\tau$, direct solution of the equations using linear algebra is not possible.
A gradient descent approach might work well.
To apply it though, we need the following partial derivatives (arguments to Y and H suppressed for brevity):
\[ \frac{\partial V}{\partial N} = \sum_{k=0}^{B-1} 2\left(H-Y\right)\frac{\partial H}{\partial N} = 2 p \sum_{k=0}^{B-1} (H-Y)(1-p)^k \]
using the chain rule.
\[ \frac{\partial V}{\partial \tau} = \sum_{k=0}^{B-1} 2\left(H-Y\right) \frac{\partial H}{\partial p} \frac{\partial p}{\partial \tau} \]
\[ = 2N\sum_{k=0}^{B-1} (H-Y)( (1-p)^k - k(1-p)^{k-1}p ) e^{-b/\tau} \frac{b}{\tau^2} \]
\[ = 2N \frac{b}{\tau^2} \sum_{k=0}^{B-1} (H-Y)( (1-p)^{k+1} - k(1-p)^{k}p ) \]
since $ e^{-b/\tau} = (1-p)$, and
\[ \frac{\partial V}{\partial \nu} = \sum_{k=0}^{B-1} 2\left(H-Y\right)\frac{\partial H}{\partial \nu} = 2\sum_{k=0}^{B-1} (H-Y) \]
\[ = 2B(\frac{1}{B}\sum_{k=0}^{B-1} H - \frac{1}{B}\sum_{k=0}^{B-1} Y) = 2B(\bar{H} - \bar{Y}) \]
This last equation is particularly simple: it tells us that the minimum variance value of $\nu$,
given some fixed $N$ and $\tau$, is the value that makes the average $H$ equal the average $Y$.
So it might also be possible to use a hybrid approach,
where we use gradient descent at each step for $N$ and $\tau$, and then solve exactly for the best $\nu$.

\subsection{Gradient descent: Implementation and results}

We implemented the above approach in GNU Octave, a Matlab clone\cite{GNUOctave,wikiOctave}.
Convergence on the $N$ and $\tau$ terms was much slower than on the $\nu$ term.
By itself, $\nu$ converged in 5 to 10 iterations as long as the descent scaling factor $\alpha$ was 0.005 to 0.009.
At $\alpha=0.01$, it showed signs of overshooting and oscillation; much higher than that and it failed to converge at all.
On the other hand, at $\alpha=0.009$, $N$ and $\tau$ took a few million iterations to converge;
a higher $\alpha$ could have sped this up.

We ran this process for 10 million iterations with $\alpha=0.009$ on each of the data sets in Table 2 that had more than 1000 decays,
resulting in Table 3.
The last row (labeled Z$_{all}$) is the union of my 3 data sets.
\begin{figure}[hbtp]

% This next "rubric" seems silly, but also works as long as included in a figure environment
%\centerline{
%\pdfximage
%width 5 in {data/ZZ.pdf}
%\pdfrefximage
%\pdflastximage }
\end{figure}
Each run took about 82 minutes on a MacBook Pro 5.1 (2.53 GHz Intel Core 2 Duo) with 4 GB memory.
Only 1 of the 2 processors was utilized, since Octave does not multiprocess.
The first 3 bins of each data set were discarded (for reasons discussed above),
leaving 997 bins each still 20 nS wide,
with all the remaining decay times effectively reduced by 60 nS to match.
This preprocessing was done by a Perl script,
which wrote out a text file that could be read into Octave as an array.
The array contained only the number of decay events for each bin,
and not any individual events;
this collective data is what the gradient descent attempted to fit.
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

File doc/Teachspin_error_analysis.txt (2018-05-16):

John, Stuart,

Here are all the sources of error I can think of in the Teachspin experiment.

(1) Decay offset due to different natures of stopping and decaying events.
The light from the stopping event is generated BEFORE the muon stops, while it is still moving.  Since the pulse detector works on the leading edge of both, that means it starts counting the lifetime too soon.  If the muon is still moving, there may be some SR time dilation that would lengthen its lifetime.
The light from the decaying event is measured AFTER the muon decays and is mostly generated by the electron produced.
NET EFFECT: Should make measured lifetimes longer than actual ones.  Rough order of magnitude would be the width of the stopping pulse.

(2) Error due to variability in pulse size/shape. (2a stopping pulse, 2b decay pulse)
Since the discriminator circuit is tuned to a specific voltage level, and the leading edge has finite slope, and the pulse shape may vary, and the size of the pulse may vary, we would expect a larger pulse to trigger slightly sooner than a smaller pulse.
NET EFFECT: Random errors in the time that the pulse is detected.  Min to max range would be somewhat less than half the typical pulse width (soonest would be the point where the largest pulse triggers, latest would be near the middle (top) of a small pulse just barely able to trigger).
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

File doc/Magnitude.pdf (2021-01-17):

International Journal of Theoretical Physics manuscript No. (will be inserted by the editor)

### The magnitude of electromagnetic time dilation

Howard A. Landman

Received: date / Accepted: date

Abstract Theories unifying gravity and electromagnetism naturally give rise to the question of whether there is a time-dilation-like effect associated with the electromagnetic 4-potential. This notion has been widely rejected, but a handful of
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

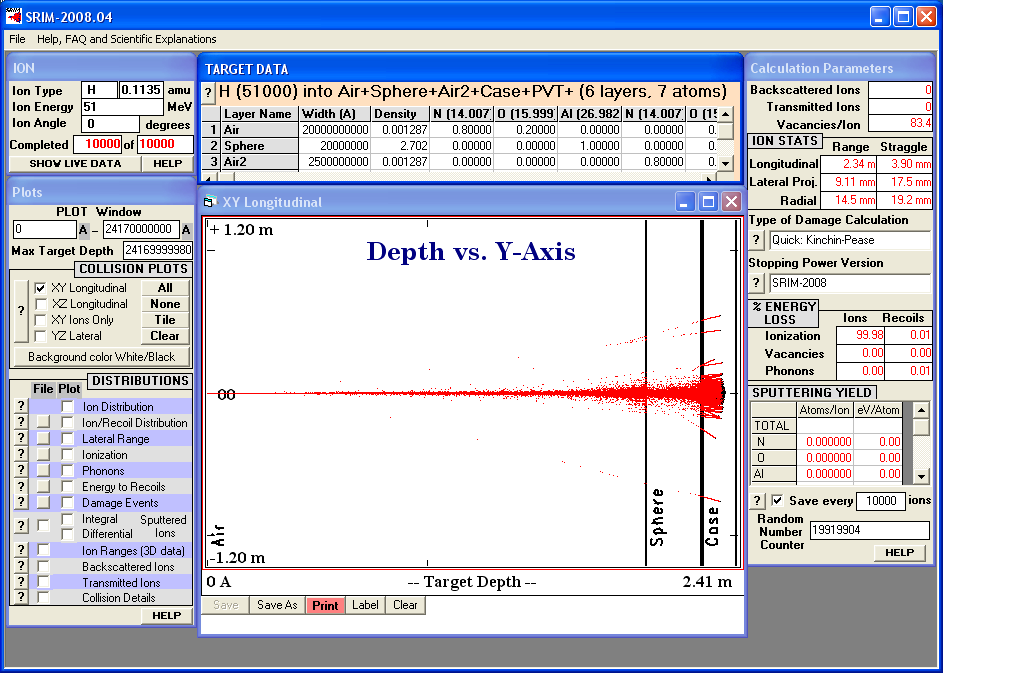
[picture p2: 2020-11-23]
Teachspin/TRIM_sphere.PNG

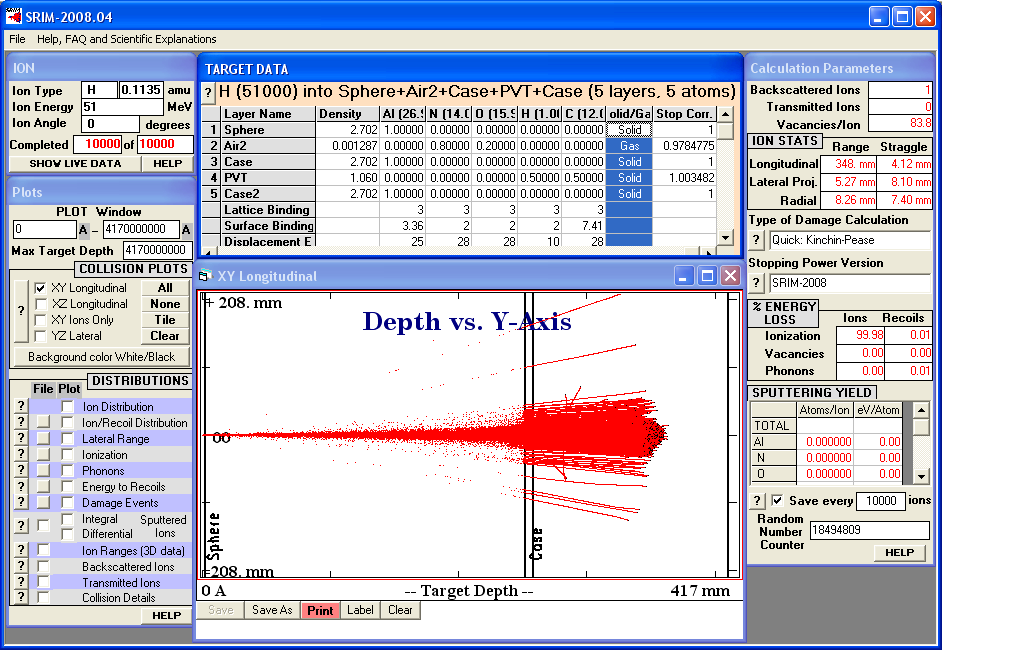
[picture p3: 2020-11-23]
Teachspin/TRIM_TeachSpin.PNG

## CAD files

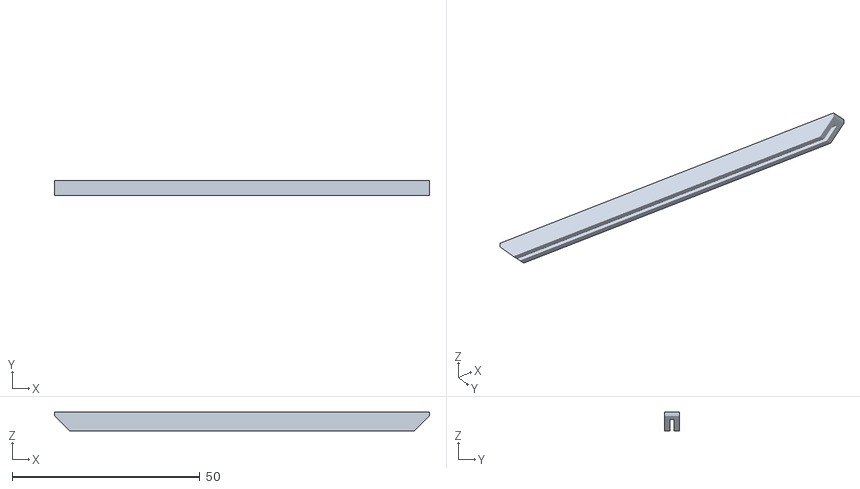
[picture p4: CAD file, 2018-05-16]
3D_printing/detector_slot.stl
100.0 x 4.00 x 5.00

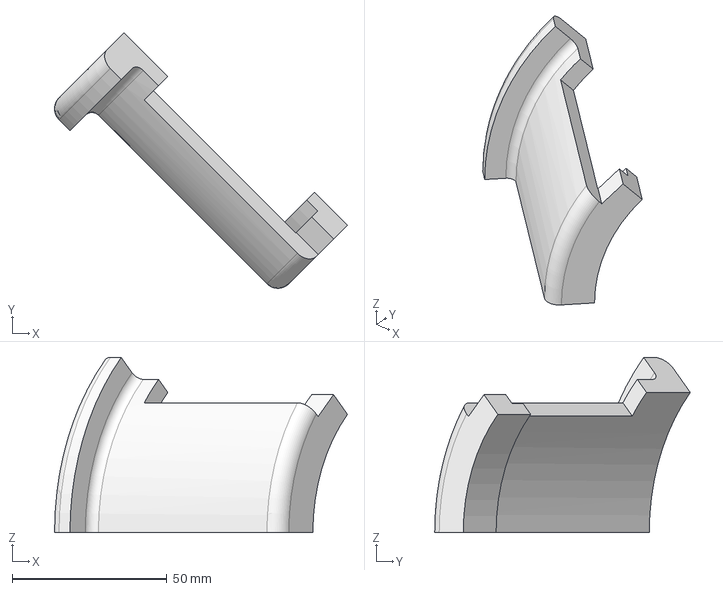
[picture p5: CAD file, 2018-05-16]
3D_printing/sphere_support_cyls4_w4.FCStd
94.7 x 82.6 x 56.6 mm

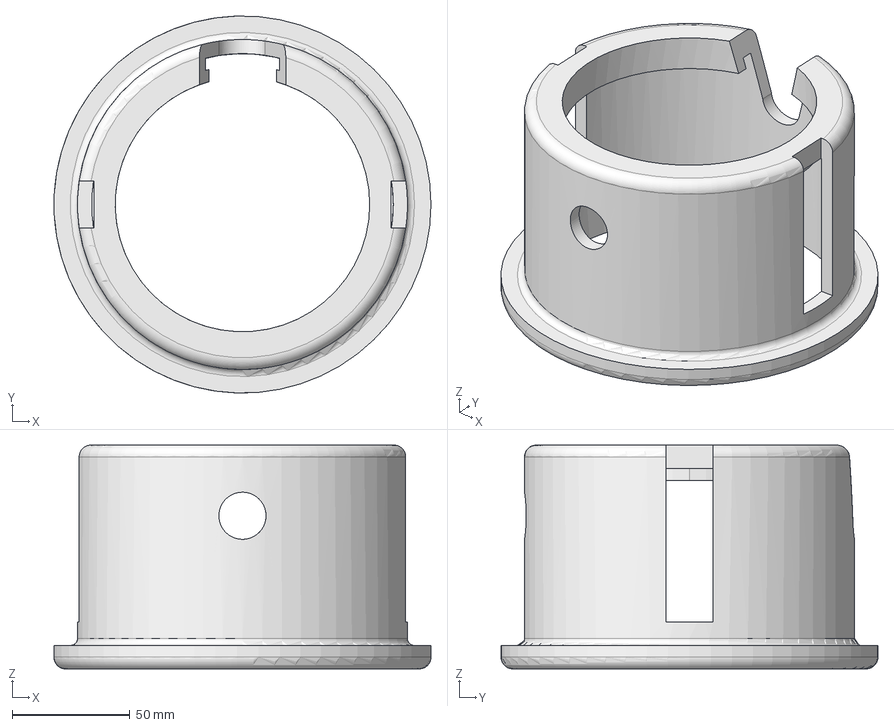
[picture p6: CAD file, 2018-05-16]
3D_printing/sphere_support_cyls4.FCStd
160.0 x 159.9 x 95.0 mm

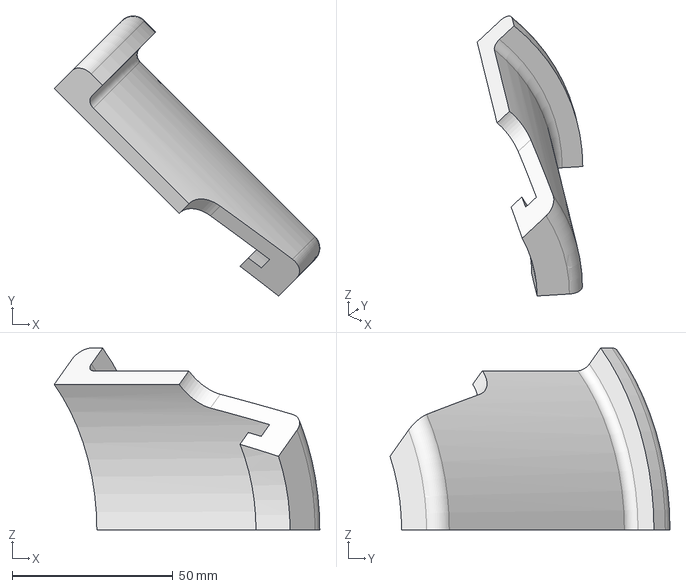
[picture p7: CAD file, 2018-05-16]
3D_printing/sphere_support_cyls4_w1.FCStd
82.6 x 87.1 x 56.6 mm

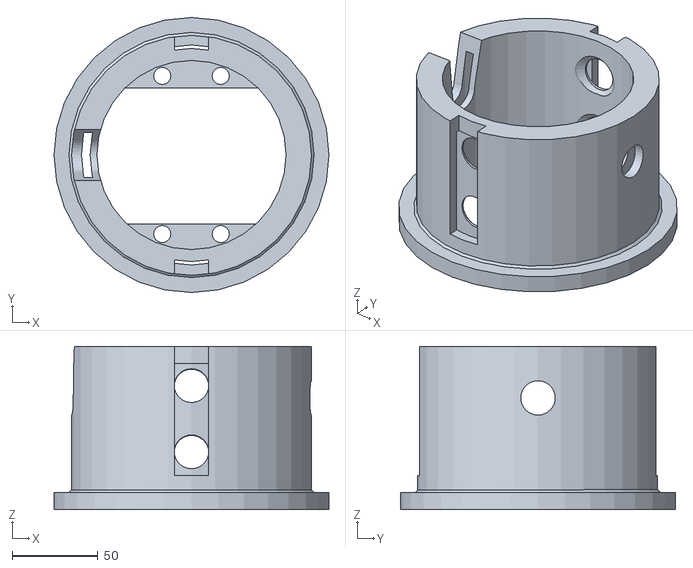
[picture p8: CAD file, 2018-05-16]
3D_printing/sphere_support.stl
160.0 x 160.0 x 95.0

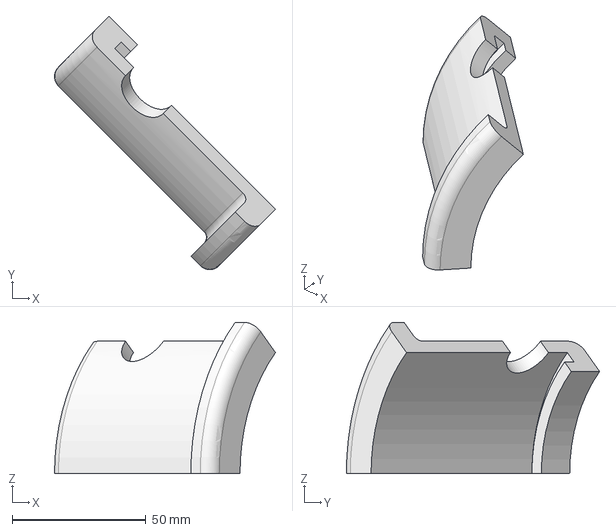
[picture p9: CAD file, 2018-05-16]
3D_printing/sphere_support_cyls4_w5.FCStd
82.6 x 94.7 x 56.6 mm

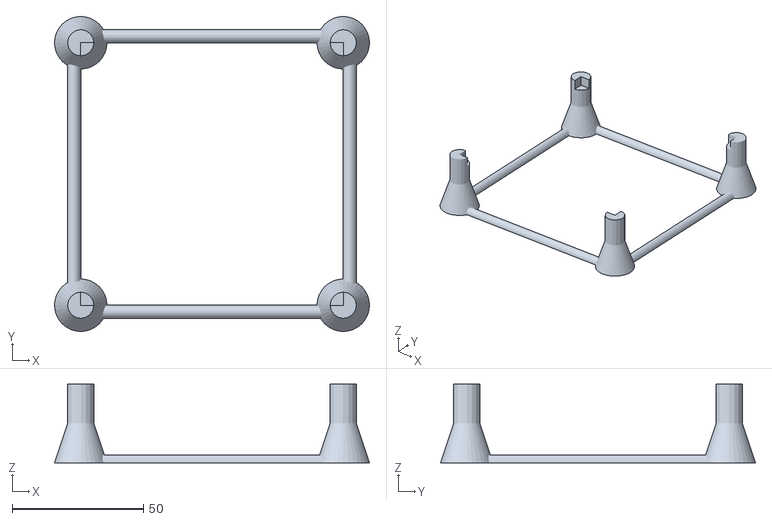
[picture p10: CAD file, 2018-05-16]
3D_printing/plate_support_25_mm.stl
120.0 x 120.0 x 30.0

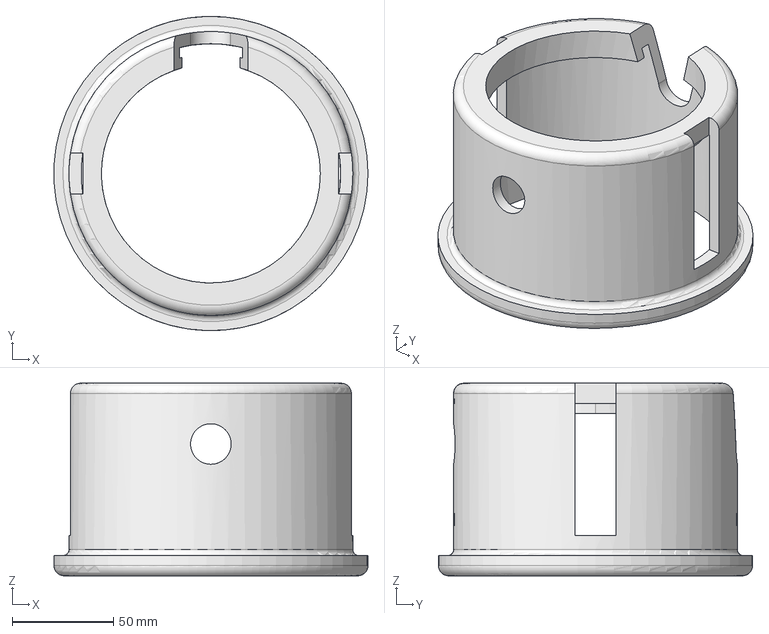
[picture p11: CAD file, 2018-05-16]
3D_printing/sphere_support_cyls3g.step
154.9 x 154.9 x 95.0 mm

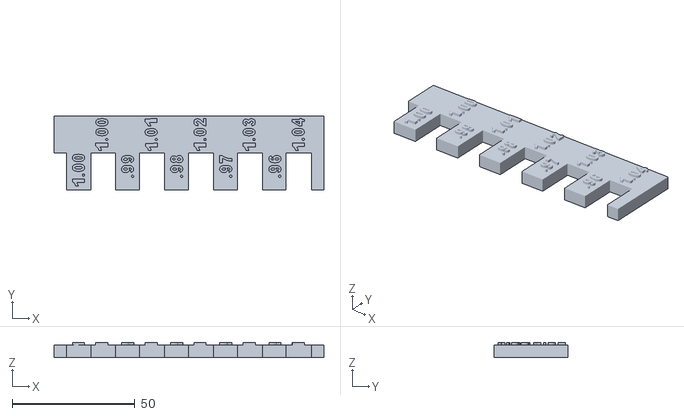
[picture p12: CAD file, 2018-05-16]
3D_printing/tolerance_vernier.stl
110.0 x 30.0 x 6.00

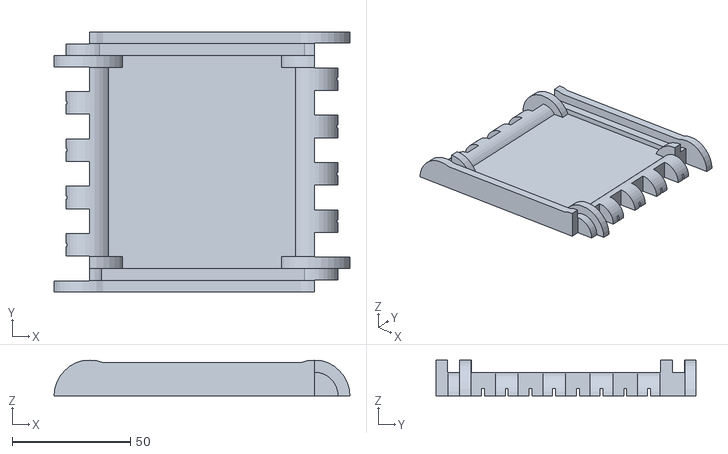
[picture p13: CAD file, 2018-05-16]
3D_printing/detector_side.stl
125.0 x 110.0 x 15.0

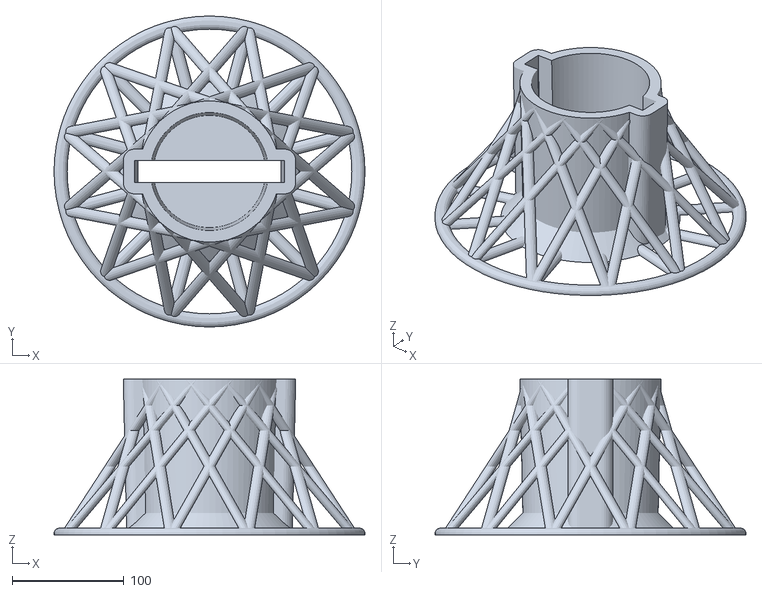
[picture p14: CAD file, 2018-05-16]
3D_printing/QTD Foam Support.stl
277.8 x 277.8 x 139.0

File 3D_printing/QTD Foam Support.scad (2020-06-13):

// Support structure for 1/4" foamboard QTD experiment base
height=139;     // 160 to equator, minus 15 for flange, minus 6 for foam thickness
angle=30;
r_max = 133;    // Lulzbot Taz bed size is nominally 280 x 280, so r_max < 140.
                // 135 was too big (slicer wouldn't accept). 134 was marginal.
r_mink = 5;     // Radius of rounding in minkowski.
r_ring = r_max - r_mink; // Outside radius of ring before minkowski
r_contact = 63; // radius of "top" surface that contacts sphere support
fillet = 3;     // radius of rounding in negative minkowski

// Now we need to compute the strut transform parameters.
// This is a little tricky.
r_strut = 5;
// Aim for making the top of the strut just tangent to the inner cylinder.
// But adjust for strut diameter.
// Since the tangent point makes a right triangle with the center and strut point,
// we can compute all the lengths.
// h = strut base to center = r_ring - 1
strut_h = r_ring - 1;
// b = tangent to center = r_contact - r_strut
strut_b = r_contact - r_strut;
// Given the hypotenuse and one side, compute the remaining side.
strut_a = sqrt(strut_h*strut_h - strut_b*strut_b);
// Find sin and cos of angle in base plane at strut base.
strut_cos = strut_a / strut_h;
strut_sin = strut_b / strut_h;
// Compute the necesary deltas in X and Y.
strut_dx = strut_a * strut_cos;
strut_dy = strut_a * strut_sin;
// Compute the corresponding transform parameters.
strut_cx = strut_dx / height;
strut_cy = strut_dy / height;
// Transform for struts tilted left.
ML = [[  1,   0, -strut_cx, 0  ],
      [  0,   1, -strut_cy, 0  ],
      [  0,   0, 1,         0  ],
      [  0,   0, 0,         1  ]] ;
// Transform for struts tilted right. Same as left, except for sign of Y.
MR = [[  1,   0, -strut_cx, 0  ],
      [  0,   1,  strut_cy, 0  ],
      [  0,   0, 1,         0  ],
      [  0,   0, 0,         1  ]] ;
      
// Transform to taper central slot
// It needs to be 133+ at "top" here and 128+ at "bottom".
// This changes over "height" variable.
// So X=64 needs to scale to X=67
slot_x_bot = 128;
slot_x_top = 134;
slot_y = 21;    // 20 was a tight fit before acetone vapor bath, jammed after.
slot_delta_x = (slot_x_top - slot_x_bot) / 2;
slot_slope = slot_delta_x / height;
MSL = [[  1,   0, slot_slope, 0  ],
      [  0,   1, 0,          0  ],
      [  0,   0, 1,          0  ],
      [  0,   0, 0,          1  ]] ;
MSR = [[  1,   0, -slot_slope, 0  ],
      [  0,   1, 0,          0  ],
      [  0,   0, 1,          0  ],
      [  0,   0, 0,          1  ]] ;

hpf = height + fillet;  // Use increased height for things that will be filleted down.

difference() {
    // main body as a solid
    difference() {
        cylinder(r=140,h=hpf+1);    // Maybe h=height or height+1 would be OK?
        minkowski() {
            difference() {
                cylinder(r=143,h=hpf+2);
                union() {
                    // main cylinder is slightly conical to match slope of bracket hull
                    cylinder(r1=r_contact-slot_delta_x+fillet,r2=r_contact+fillet,h=hpf,$fa=5);
                    //translate([0,0,height-40]) cylinder(r1=0,r2=69,h=40,$fa=5);
                    // flare at base
                    cylinder(r1=80+fillet,r2=0,h=80+fillet,$fa=5);
                    //cylinder(r=135,h=2);
                    // bracket hull
                    hull() {
                        hull_x = slot_x_bot / 2;
                        hull_y = slot_y / 2;
                        multmatrix(MSL) translate([ hull_x, hull_y,0]) cylinder(r=10+fillet,h=hpf);
                        multmatrix(MSL) translate([ hull_x,-hull_y,0]) cylinder(r=10+fillet,h=hpf);
                        multmatrix(MSR) translate([-hull_x, hull_y,0]) cylinder(r=10+fillet,h=hpf);
                        multmatrix(MSR) translate([-hull_x,-hull_y,0]) cylinder(r=10+fillet,h=hpf);
                    }
                    // base
                    minkowski() {
                        union() {
                            // base ring
                            difference() {
                                cylinder(r=r_ring,h=1,$fa=5);
                                cylinder(r=r_ring-2,h=10,center=true,$fa=5);
                            }
                            // base radial struts
                            for(a = [angle/2 : angle : 180]) {
                                rotate([0,0,a]) translate([0,0,0.5]) cube([2*strut_h,1,1],center=true);
                            }
                        }
                        // hemisphere to round everything
                        intersection() {
                            sphere(r=r_mink+fillet,$fa=10);
                            cylinder(r=r_mink+fillet+1,h=r_mink+fillet+1);
                        }
                    }
                    // Hyperboloid struts
                    for(a = [angle/2 : angle : 360]) {
                        rotate([0,0,a]) union() {
                            // left leaning struts
                            multmatrix(ML) {
                                translate([strut_h,0,0]) cylinder(r=5+fillet,h=height,$fa=10);
                            }
                            // right leaning struts
                            multmatrix(MR) {
                                translate([strut_h,0,0]) cylinder(r=5+fillet,h=height,$fa=10);
                            }
                            // hemisphere at join
                            //translate([strut_h,0,0]) intersection() {
                            //    sphere(r=8,center=true,$fa=10);
                            //    cylinder(r=11,h=11);
                            //}
                        }
                    }
                }
            }
            sphere(r=fillet);
        }
    }
    // things to cut out
    union() {
        // slot for metal straps
        multmatrix(MSL) { cube([slot_x_bot,slot_y,300],center=true); }
        multmatrix(MSR) { cube([slot_x_bot,slot_y,300],center=true); }
        // central cylindrical hole
        translate([0,0,10]) cylinder(r1=53-slot_delta_x,r2=53,h=height,$fa=5);
    }
}

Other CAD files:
3D_printing/sphere_support_cyls4_w6.FCStd
3D_printing/sphere_support_cyls4_w3.FCStd
3D_printing/sphere_support_cyls4_w2.FCStd
3D_printing/sphere_support_cyls3g.FCStd
3D_printing/sphere_support_cyls4_w1.stl
3D_printing/sphere_support_cyls4_w2.stl
3D_printing/sphere_support_cyls4_w3.stl
3D_printing/sphere_support_cyls4_w4.stl
3D_printing/sphere_support_cyls4_w5.stl
3D_printing/sphere_support_cyls4_w6.stl

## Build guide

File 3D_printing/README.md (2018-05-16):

# 3D Printing
Some parts of the experimental equipment will be 3D printed.
This directory holds the relevant files, but the original source may be elsewhere.

## Plate support (25 mm)
### A first experiment, just a stand for a 10 cm plate
Source: https://www.tinkercad.com/things/kLAUk3VosVy
Print data: plate_support_35_mm.stl
Mass (HIPS): 15 grams

## Detector slot
### A piece of the detector frame, intended to support one edge of a plate
### Not useful in itself, just for checking printing tolerances.
Source: https://www.tinkercad.com/things/18zoNqxYxV9
Print data: detector_slot.stl

## Detector side
### One side of detector structural prototype.
### Four of these together (with a couple of cable ties) make a complete frame.
Source: https://www.tinkercad.com/things/4ILyVpeohzc (rev 1)
Source: https://www.tinkercad.com/things/1xpw5McpMiS (rev 2)
Source: https://www.tinkercad.com/things/3n5bOw2piaQ (rev 3)
Print data: detector_side.stl

## Tolerance vernier
### A simple test piece for printing tolerances.
### Various nominal size tabs and slots in 0.1 mm increments.
### Print two of these and try to fit them together.
Source: https://www.tinkercad.com/things/7GUWB093loK
Print data: tolerance_vernier.stl

## Sphere support
### Designed to fit over the column head of my Van De Graff Generator
### and provide a support ring for the botton of the sphere
### (which will be in hemispheres and cannot be suspended from the top
### like a single sphere.)
Source: https://www.tinkercad.com/things/9SgI5MTNfcd
Print data: sphere_support.stl

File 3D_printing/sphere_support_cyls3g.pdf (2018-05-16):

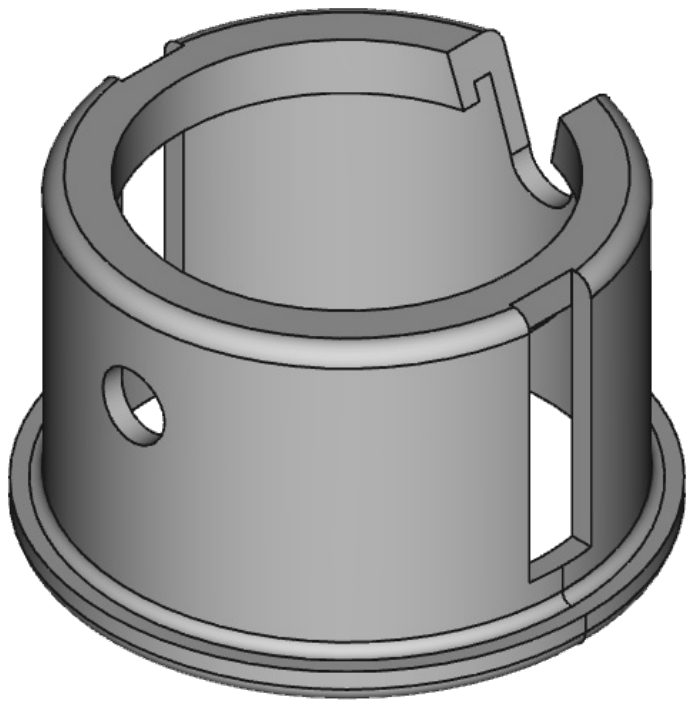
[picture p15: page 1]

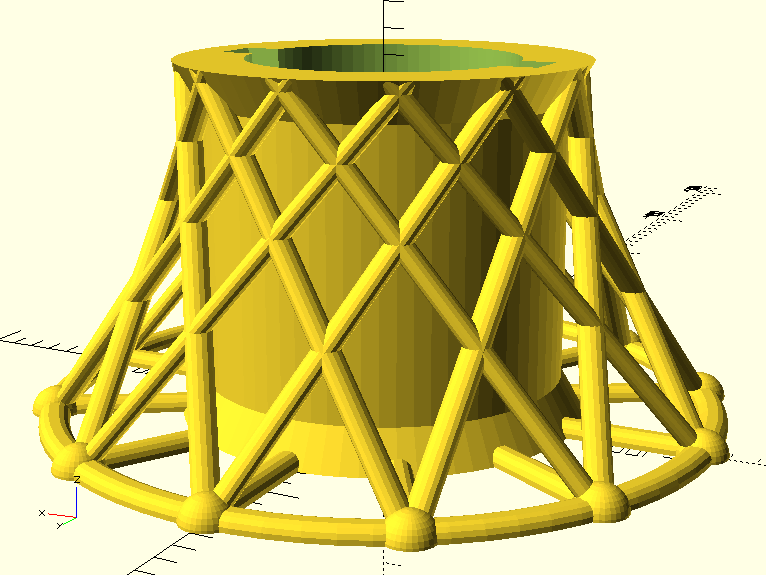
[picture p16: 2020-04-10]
3D_printing/QTD Foam Support.png

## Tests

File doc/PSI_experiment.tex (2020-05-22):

\documentclass[12pt]{amsart}
\usepackage{geometry} % see geometry.pdf on how to lay out the page. There's lots.
\geometry{a4paper} % or letter or a5paper or ... etc
% \geometry{landscape} % rotated page geometry
\usepackage{url}
\usepackage{amsthm}
%\usepackage{lineno} % Nature Physics requires line numbers

% PSI wants sans-serif fonts like Arial or Helvetica
\renewcommand*\familydefault{\sfdefault} 

% See the ``Article customise'' template for come common customisations

   % The amssymb package provides \mathbb and other
   % math symbols.  The amsmath package provides sophisticated math
   % constructions.  The amsthm package provides \theoremstyle and
   % the \proof environment.
   %
   % The amsmath and amsthm packages are automatically activated by
   % \documentclass{amsart}, so there is no need to activate them here.

      \usepackage{amssymb}

   % Next we use \newtheorem to specify our theorem-like environments
   % (theorem, definition, etc.) and how to display and number them.
   %
   % Note: The \theoremstyle declarations affect the appearance of the
   % Theorems, Definitions, etc.

      \theoremstyle{plain}
      \newtheorem{theorem}{Theorem}[section]
      \newtheorem{lemma}[theorem]{Lemma}
      \newtheorem{corollary}[theorem]{Corollary}
      
      \theoremstyle{definition}
      \newtheorem{definition}[theorem]{Definition}
      
      \theoremstyle{remark}
      \newtheorem{remark}[theorem]{Remark}

   % The preamble is also a good place to define new commands and macros.
   % This part of the preamble is strictly optional according to your taste.

      \newcommand{\R}{{\mathbb R}}
      \newcommand{\nil}{\varnothing}

   % The following mysterious maneuver gets rid of AMS junk at the top
   % and bottom of the first page.
   
      \makeatletter
      \def\@setcopyright{}
      \def\serieslogo@{}
      \makeatother

  \fontfamily{Arial}
%  \fontseries{m}
%  \fontshape{it}
%  \fontsize{12}{15}
  \selectfont

\title{Electrostatic time dilation.}
\author{Howard A. Landman}
\date{v1.1\ \today} % delete this line to display the current date

%%% BEGIN DOCUMENT
\begin{document}
\maketitle

%\begin{affiliations}
% \item Fort Collins, Colorado, USA \ howard@riverrock.org
%\end{affiliations}

\begin{abstract}
We propose to test the existence of an electromagnetic time dilation
by measuring the decay lifetimes of muons inside a charged Van de Graaff generator.

\end{abstract}

%\tableofcontents

\section{Theoretical background}

Several unified theories\cite{Apsel1978,Apsel1979,Apsel1981,Rodrigues1983,Ryff1985,Beil1987,Dubey2015,Ogonowski2012}
predict a time dilation associated with the electromagnetic 4-potential.
My own work\cite{Landman2017,Landman2020} confirms the approximate magnitude of this effect (ignoring the magnetic part, which is very tiny) as
\[ T_d =  e^{qV/mc^2} \approx  1 + \frac{qV}{mc^2} \]
The philosophical question here is whether EM acceleration is "gravity-like",
i.e. whether the Equivalence Principle applies to EM.
This is a yes/no question with only two possible answers.
If it does, then application of Einstein's 1907 derivation\cite{Einstein1907} forces EM time dilation,
and gives a magnitude identical to the above.
If it doesn't, then there can be no EM time dilation.
Weyl was perhaps the only early theorist to explicitly consider this question, and assumed that it doesn't\cite[pp. 304-305]{Weyl1923};
most other researchers implicitly assume the same without even discussing it.
We propose to test whether they were right to do so.

%There is a curious paradox hidden in the above results.
%$\nu = E/h$ implies that in QM the (quantum phase) frequency of things is linearly proportional to their energy.
%$T_d = e^{ gz/c^2 } = e^{ mgz/mc^2 }$ implies that in GR
%the (time-dilated) frequency of things is an exponential function of their energy.
%Both formulae are widely accepted, but
%it seems obvious that they cannot both be universally true.
%Reconciling this apparent contradiction is beyond the scope of the current paper.

\section{Why muons?}

Unlike in the gravitational case,
%where gravitational mass and inertial mass cancel out,
here both charge and mass matter,
or more precisely the dilation is a function of the charge/mass ratio $q/m$.
Uncharged particles should be completely unaffected.
For a given non-zero $q$, lighter particles will be dilated more strongly than heavier particles.

Thus, for experimental testing, we are lead to the muon.
With a mass-energy of $m_\mu c^2 = 105.7\ \textup{MeV}$,
it is still light enough to have its mean lifetime of $2.2\ \mu \textup{S}$
affected by a modest potential.
For example, a potential of 1.057 MV should alter its lifetime by about 1\%.
Apsel first proposed this kind of experiment in 1979\cite{Apsel1979};
40 years later it still has never been performed.

Charged pions ($\pi^+$, $\pi^-$) have a charge-mass ratio 0.757 as large as a muon's,
and would also be reasonable for such experiments, but would require about
$0.757^{-2} = 1.75$ times as many data points to get the same statistical significance.

\section{Experimental setup}

BEAM: A beam of low energy (around 10-60 MeV/c) $\mu^+$
is delivered to the detector.
Surface $\mu^+$ at ~28 MeV/c would be fine.
Beam diameter just needs to be smaller than the scintillator,
so anything under about 150 mm should be OK.
The "muon on request" system might be good, but I need more technical details.
Otherwise the beam could be continuous with a current of perhaps 100 to 500 $\mu^+$/S.
The center of the beam (if horizontal) will need to enter the VDGG at approximately 1.2 m above the floor.

SPACE: A gap of at least 0.5 to 1 m must exist between any conductive part of the beam system (or other experimental devices) and the VDGG sphere to prevent arcing. 2 m or greater is recommended.

VDGG: The current Van De Graaff Generator is a 700 kV kit\cite{PP700kV} from Physics Playground, modified to have a sphere made from 2 hemispheres for easy access to the interior.
The sphere is 507 mm diameter and is made from stainless steel approximately 1.5 mm thick (except where the overlap flange exists near the seam, where it is about double that).
A foamboard work platform supported by 3D-printed struts is mounted just below the seam;
all the internal devices sit on that.
A grounding wand for the sphere will be mounted nearby,
and must be used to discharge the sphere before any maintenance.
The VDGG polarity can be reversed by swapping rollers,
but this requires disassembling the sphere and takes about 1 hour.

SCINTILLATOR: The scintillator unit will be a cylinder of plastic scintillator + PMT + high-voltage circuitry, enclosed in a lightproof metal case.
At the moment this will probably be the scintillator portion
of a Teachspin student muon lifetime experiment,
as we have experience with that and it is adequate.
It is 16.5 cm diameter by 36 cm tall.
The scintillator requires a DC power supply (not yet specified).

PULSE-PAIR TIMER: Our current prototype uses a Texas Instruments TDC7201 chip.\cite{TDC7201}
There may have to be some preprocessing circuitry between the scintillator output and it.
The chip SPI interface is driven by a Raspberry Pi 0W,
which does control, data logging, and status reporting via MQTT.
Current software in Python3 can run about 500 simulated measurements per second.
The Pi is powered by an Adafruit UPS board with LiPo batteries
plus a 10 AH or greater USB battery bank,
so that the bank can be swapped out without powering down the Pi.
Power consumption is 0.20 A, which should allow about 50 hours runtime.

FIELD METER: An external chopper-stabilized electric field meter will be used to monitor the sphere voltage. It should be re-calibrated to a voltage standard while in the PSI environment. Two such meters are currently being evaluated.

OTHER METERS: Temperature and humidity should also be logged, as they could affect the voltage on the sphere.
We can even do that inside the sphere by hanging I2L sensors off the Pi.

The above would suffice.
More external instruments could be used;
however, communication between internal and external devices
could NOT be done over metal wires,
but would have to be via wifi (already demonstrated to work), fiber optics, or something else non-conductive.

Project source code is available on github.\cite{qtd_github}
The tdc7201 driver is also available on Pypi as a Python 3 module via "python3 -m pip install tdc7201".

\section{Beam time estimate}

(These need to be checked.)
Under optimistic assumptions (+-700 kV; about 3.7\% of decays lost; 500 $\mu^+$/S)
it would take about 1.3M $\mu^+$ and about 0.75 hours of beam time to reach 5 sigma
that positive and negative potentials dilate muons oppositely (one two-tailed test).
Under more pessimistic assumptions (+500 kV, 0, -500 kV; 13\% of decays lost; 100 $\mu^+$/S)
it would take about 16.1M $\mu^+$ and about 44.7 hours of beam time to reach 5 sigma
that each of positive and negative potentials differ from the 0V base case (two one-tailed tests).
These estimates ignore noise from background radiation, cosmic rays, and beam impurities.

If there is time, it would be good to repeat the entire experiment with negative $\mu^-$
to show that they are dilated by the same amount but in the opposite direction.
This would require a similar amount of time on a $\mu^-$ beam.

\begin{thebibliography}{10}

\bibitem{Apsel1978}
D. Apsel,
``Gravitational, electromagnetic, and nuclear theory'',
{\em 	International Journal of Theoretical Physics} v.17 \#8 643-649 (Aug 1978)
DOI: 	10.1007/BF00673015

\bibitem{Apsel1979}
D. Apsel,
``Gravitation and electromagnetism'',
{\em General Relativity and Gravitation} v.10 \#4 297-306 (Mar 1979)
DOI: 10.1007/BF00759487

\bibitem{Apsel1981}
D. Apsel,
``Time dilations in bound muon decay'',
{\em General Relativity and Gravitation} v.13 \#6 605-607 (Jun 1981)
DOI: 10.1007/BF00757247

\bibitem{Rodrigues1983}
W.A. Rodrigues Jr.,
``The Standard of Length in the Theory of Relativity and Ehrenfest Paradox'',
{\em Il Nuovo Cimento} v.74 B \#2 199-211 (11 April 1983)

\bibitem{Ryff1985}
L.C.B. Ryff,
``The Lifetime of an Elementary Particle in a Field'',
{\em General Relativity and Gravitation} v.17 \#6 515-519 (1985)

\bibitem{Beil1987}
R.G. Beil,
``Electrodynamics from a Metric'',
{\em Int. J. of Theoretical Physics} v.26 \#2 189-197 (1987)

%\bibitem{vanHolten1991}
%J.W. van Holten,
%``Relativistic Time Dilation in an External Field'',
%NIKHEF-H/91-05 (1991)

%\bibitem{vanHolten1993}
%J.W. van Holten,
%``Relativistic Dynamics of Spin in Strong External Fields'',
%\url{arXiv:hep-th/9303124v1}, (24 March 1993)

\bibitem{Dubey2015}
A.K. Dubey, A.K. Sen,
``Gravitational Redshift in Kerr-Newman Geometry'',
\url{arXiv:1503.03833v5}, (16 October 2015)

\bibitem{Ogonowski2012}
P. Ogonowski,
``Time dilation as field'',
Journal of Modern Physics, 3, 200-207 (2012)

%\bibitem{Ogonowski2013}
%P. Ogonowski, P. Skindzier,
%``Maxwell-like picture of General Relativity and its Planck limit'',
%\url{https://arxiv.org/pdf/1301.2758.pdf}

\bibitem{Landman2017}
H. Landman,
"An elementary approach to quantum time dilation",
\url{http://www.riverrock.org/~howard/QuantumTime29.pdf}

\bibitem{Landman2020}
H. Landman,
"The magnitude of electromagnetic time dilation",
\url{http://www.riverrock.org/~howard/Magnitude_4_3.pdf}

\bibitem{Einstein1907}
A. Einstein, ``\"{U}ber das Relativit\"{a}tsprinzip und die aus demselben gezogenenn Folgerungen'',
{\em Jahrbuch der Radioaktivit\"{a}t und Elektronik} 4, 411-462 (4 December 1907);
English translation, ``On the relativity principle and the conclusions drawn from it'',
{\em The Collected Papers}, v.2, 433-484 (1989),
available at \url{https://einsteinpapers.press.princeton.edu/vol2-trans/319}

\bibitem{Weyl1923}
H. Weyl,
{\em Raum-Zeit-Materie} 6th ed.,
Springer-Verlag (18 Apr 1923)

%\bibitem{PDG2014}
%K.A. Olive et al. (Particle Data Group),
%Chin. Phys. C38, 090001 (2014)
%\url{http://pdg.lbl.gov/2014/listings/rpp2014-list-muon.pdf}

\bibitem{PP700kV}
\url{https://www.physicsplayground.com/apps/webstore/products/show/1083379}

\bibitem{TDC7201}
"TDC7201 Time-to-Digital Converter for Time-of-Flight Applications in LIDAR, Range Finders, and ADAS",
\url{http://www.ti.com/lit/ds/symlink/tdc7201.pdf} (May 2016)

\bibitem{qtd_github}
\url{https://github.com/HowardALandman/QTD}

\end{thebibliography}

\end{document}

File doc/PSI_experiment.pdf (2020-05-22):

ELECTROSTATIC TIME DILATION.

HOWARD A. LANDMAN

Abstract. We propose to test the existence of an electromagnetic time dilation by measuring the decay lifetimes of muons inside a charged Van de Graaff generator.

1. Theoretical background

Several unified theories[1, 2, 3, 4, 5, 6, 7, 8] predict a time dilation associated with the electromagnetic 4-potential. My own work[9, 10] confirms the approximate magnitude of this effect (ignoring the magnetic part, which is very tiny) as

Td = e

qV /mc²
≈ 1 +

qV
mc²
The philosophical question here is whether EM acceleration is ”gravity-like”, i.e. whether the Equivalence Principle applies to EM. This is a yes/no question with only two possible answers. If it does, then application of Einstein’s 1907 derivation[11] forces EM time dilation, and gives a magnitude identical to the above. If it doesn’t, then there can be no EM time dilation. Weyl was perhaps the only early theorist to explicitly consider this question, and assumed that it doesn’t[12, pp. 304-305]; most other researchers implicitly assume the same without even discussing it. We propose to test whether they were right to do so.
2. Why muons?

Unlike in the gravitational case, here both charge and mass matter, or more precisely the dilation is a function of the charge/mass ratio q/m. Uncharged particles should be completely unaffected. For a given non-zero q, lighter particles will be dilated more strongly than heavier particles.
Thus, for experimental testing, we are lead to the muon. With a mass-energy of mµc

2 = 105.7 MeV, it is still light enough to have its mean lifetime of 2.2 µS affected by a modest potential. For example, a potential of 1.057 MV should alter its lifetime by about 1%. Apsel first proposed this kind of experiment in 1979[2]; 40 years later it still has never been performed.
Charged pions (π

+, π

−) have a charge-mass ratio 0.757 as large as a muon’s, and would also be reasonable for such experiments, but would require about 0.757⁻² = 1.75 times as many data points to get the same statistical significance.

Date: v1.1 May 19, 2020.
1

2 | HOWARD A. LANDMAN
3. Experimental setup

BEAM: A beam of low energy (around 10-60 MeV/c) µ

+ is delivered to the detector. Surface µ

+ at 28 MeV/c would be fine. Beam diameter just needs to be smaller than the scintillator, so anything under about 150 mm should be OK. The ”muon on request” system might be good, but I need more technical details. Otherwise the beam could be continuous with a current of perhaps 100 to 500 µ

+/S. The center of the beam (if horizontal) will need to enter the VDGG at approximately 1.2 m above the floor. SPACE: A gap of at least 0.5 to 1 m must exist between any conductive part of the beam system (or other experimental devices) and the VDGG sphere to prevent arcing. 2 m or greater is recommended.
VDGG: The current Van De Graaff Generator is a 700 kV kit[13] from Physics Playground, modified to have a sphere made from 2 hemispheres for easy access to the interior. The sphere is 507 mm diameter and is made from stainless steel approximately 1.5 mm thick (except where the overlap flange exists near the seam, where it is about double that). A foamboard work platform supported by 3D-printed struts is mounted just below the seam; all the internal devices sit on that. A grounding wand for the sphere will be mounted nearby, and must be used to discharge the sphere before any maintenance. The VDGG polarity can be reversed by swapping rollers, but this requires disassembling the sphere and takes about 1 hour.
SCINTILLATOR: The scintillator unit will be a cylinder of plastic scintillator + PMT + high-voltage circuitry, enclosed in a lightproof metal case. At the moment this will probably be the scintillator portion of a Teachspin student muon lifetime experiment, as we have experience with that and it is adequate. It is 16.5 cm diameter by 36 cm tall. The scintillator requires a DC power supply (not yet specified).
PULSE-PAIR TIMER: Our current prototype uses a Texas Instruments TDC7201 chip.[14] There may have to be some preprocessing circuitry between the scintillator output and it. The chip SPI interface is driven by a Raspberry Pi 0W, which does control, data logging, and status reporting via MQTT. Current software in Python3 can run about 500 simulated measurements per second. The Pi is powered by an Adafruit UPS board with LiPo batteries plus a 10 AH or greater USB battery bank, so that the bank can be swapped out without powering down the Pi. Power consumption is 0.20 A, which should allow about 50 hours runtime.
FIELD METER: An external chopper-stabilized electric field meter will be used to monitor the sphere voltage. It should be re-calibrated to a voltage standard while in the PSI environment. Two such meters are currently being evaluated.
OTHER METERS: Temperature and humidity should also be logged, as they could affect the voltage on the sphere. We can even do that inside the sphere by hanging I2L sensors off the Pi.
The above would suffice. More external instruments could be used; however, communication between internal and external devices could NOT be done over metal wires, but would have to be via wifi (already demonstrated to work), fiber optics, or something else non-conductive.

ELECTROSTATIC TIME DILATION. | 3

Project source code is available on github.[15] The tdc7201 driver is also available on Pypi as a Python 3 module via ”python3 -m pip install tdc7201”.

4. Beam time estimate

(These need to be checked.) Under optimistic assumptions (+-700 kV; about 3.7% of decays lost; 500 µ

+/S) it would take about 1.3M µ

+ and about 0.75 hours of beam time to reach 5 sigma that positive and negative potentials dilate muons oppositely (one two-tailed test). Under more pessimistic assumptions (+500 kV, 0, -500 kV; 13% of decays lost; 100 µ

+/S) it would take about 16.1M µ

+ and about 44.7 hours of
beam time to reach 5 sigma that each of positive and negative potentials differ from the 0V base case (two one-tailed tests). These estimates ignore noise from background radiation, cosmic rays, and beam impurities.
If there is time, it would be good to repeat the entire experiment with negative µ

−
to show that they are dilated by the same amount but in the opposite direction. This would double the total beam time and might require a different beam.

References

[1] D. Apsel, “Gravitational, electromagnetic, and nuclear theory”, International Journal of Theoretical Physics v.17 #8 643-649 (Aug 1978) DOI: 10.1007/BF00673015
[2] D. Apsel, “Gravitation and electromagnetism”, General Relativity and Gravitation v.10 #4 297-306 (Mar 1979) DOI: 10.1007/BF00759487
[3] D. Apsel, “Time dilations in bound muon decay”, General Relativity and Gravitation v.13 #6 605-607 (Jun 1981) DOI: 10.1007/BF00757247
[4] W.A. Rodrigues Jr., “The Standard of Length in the Theory of Relativity and Ehrenfest Paradox”, Il Nuovo Cimento v.74 B #2 199-211 (11 April 1983)
[5] L.C.B. Ryff, “The Lifetime of an Elementary Particle in a Field”, General Relativity and Gravitation v.17 #6 515-519 (1985)
[6] R.G. Beil, “Electrodynamics from a Metric”, Int. J. of Theoretical Physics v.26 #2 189-197 (1987)
[7] A.K. Dubey, A.K. Sen, “Gravitational Redshift in Kerr-Newman Geometry”, arXiv:1503. 03833v5, (16 October 2015)
[8] P. Ogonowski, “Time dilation as field”, Journal of Modern Physics, 3, 200-207 (2012)
[9] H. Landman, ”An elementary approach to quantum time dilation”, http://www.riverrock.org/~howard/QuantumTime29.pdf
[10] H. Landman, ”The magnitude of electromagnetic time dilation”, http://www.riverrock.org/~howard/Magnitude_4_3.pdf
[11] A. Einstein, “Uber das Relativit¨atsprinzip und die aus demselben gezogenenn Folgerungen”, ¨ Jahrbuch der Radioaktivit¨at und Elektronik 4, 411-462 (4 December 1907); English translation, “On the relativity principle and the conclusions drawn from it”, The Collected Papers, v.2, 433-484 (1989), available at https://einsteinpapers.press.princeton.edu/vol2-trans/319
[12] H. Weyl, Raum-Zeit-Materie 6th ed., Springer-Verlag (18 Apr 1923)
[13] https://www.physicsplayground.com/apps/webstore/products/show/1083379
[14] ”TDC7201 Time-to-Digital Converter for Time-of-Flight Applications in LIDAR, Range Finders, and ADAS”, http://www.ti.com/lit/ds/symlink/tdc7201.pdf (May 2016)
[15] https://github.com/HowardALandman/QTD

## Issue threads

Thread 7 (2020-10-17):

Add TDC7200 support

PE1NUT, 2020-10-17:
The TDC7201 and TDC7200 are very similar ICs. The TDC7201 contains two,instead of one TDC, and has some improved parameters (higher stop count, longer time interval for mode 1, SPI clock from 20 MHz to 25 MHz). Notably, both have the same register map.

If there's interest, I can dig into the details, and provide a PR with what's needed to get the TDC7200 properly supported as well. The code as is already seems to work out-of-the-box with the TDC7200.

HowardALandman, 2020-10-17:
Thanks. I had noticed the 7200 myself recently, but don’t have one to test against, so I didn’t want to claim that it worked when I had no way of being sure.

Good 7200 support would seem to include minor changes to set_SPI_clock_speed(), different limit checks for some of the control registers, and disabling of any side 2 support.

Moayidd, 2021-08-08:
Hi,
So would this work with the tdc7200 IC (chip) on its own instead of the tdc7200EVM ? If it does could you possibly provide the pin assignment tdc72000 to GPIO of the Raspberry along with any Caps or resistors needed ? It would help tremendously as I'm really stuck with the TDC7200 chip and am very new to this.
Regards

HowardALandman, 2021-08-08:
I except that my code should probably work with the 7200 as long as the changes listed above are made. For example, the upper spec limit in set_SPI_clock_speed() should be dropped from 25 MHz to 20 MHz.

Some of the pin assignment is forced (especially power/gnd and SPI pins) and some is arbitrary (any GPIO will work). You can follow my pin assignment or you can choose your own. You'd also want to make something like [my pin table for the 7201 EVM](https://docs.google.com/spreadsheets/d/1HZRhcEi4tPff74blWr2iM1LQ2CbjEHBjNR3pyOlQMAU/edit?usp=sharing).

If you're not using the EVM's built-in clock, you'll need to provide your own clock and clock control.

It's very important that the traces for START and STOP be perfectly balanced, or else your board layout will introduce skew into the timing. You also don't want any other active signals (especially your clock!) routed anywhere near those, to avoid capacitive coupling.

Moayidd, 2021-08-09:
Thanks for all the info, I'll give your suggestions a try. When you say START and STOP traces are perfectly balanced you mean same trace length, correct ?
regards

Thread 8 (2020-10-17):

Module fails on line 237 'self._spi.cshigh = False'

PE1NUT, 2020-10-17:
When calling the constructor, it aborts with this failure message:

```
    tdc = tdc7201.TDC7201()
  File "/usr/local/lib/python3.7/dist-packages/tdc7201/__init__.py", line 237, in __init__
    self._spi.cshigh = False
```

This seems to be linked to the following issue with spidev:

https://github.com/doceme/py-spidev/issues/108

It is unclear to me at the moment whether there is a bug with the Linux kernel, python-spidev or the Raspberry Pi hardware. But on a Raspberry Pi 4B, I need to commend out line 237, and then things work. I think that cshigh is the default anyway.

HowardALandman, 2020-10-17:
I've mostly been testing on Pi3B+ rev.1.3 and Pi0W. I'll port to my 4B and see if I can reproduce.

Can SystemError be caught by a try:except: ?

Make sure you have the latest spidev (>=3.5) because there were known bugs in 3.4 that got fixed. If you installed the TDC7201 code recently, via pip3, then that dependency should be forced.

HowardALandman, 2020-10-18:
I'm not seeing this problem on my Raspberry Pi 4 Model B Rev 1.1, Raspbian GNU/Linux 10 (buster) 2019-07-10, using tdc7201==0.10.0 and spidev==3.5. What are you using?

HowardALandman, 2021-03-10:
OK, I now see this issue using tdc7201==0.11.2 on a Pi 3B+. There seem to be 2 separate issues.
1. self._spi.cshigh is reported to be True even though the default is supposed to be False. If this weren't happening, we wouldn't even bother to try to set it.
2. When we do try to set it, we get the unspecified error. It is possible to catch this and ignore it; in that case, everything seems to work fine. It also seems to work fine without setting it. So it looks like the default is actually correct, but gets reported wrong.
Neither problem happens on my Pi 4B. Maybe this is related to Raspbian version rather than CPU type?

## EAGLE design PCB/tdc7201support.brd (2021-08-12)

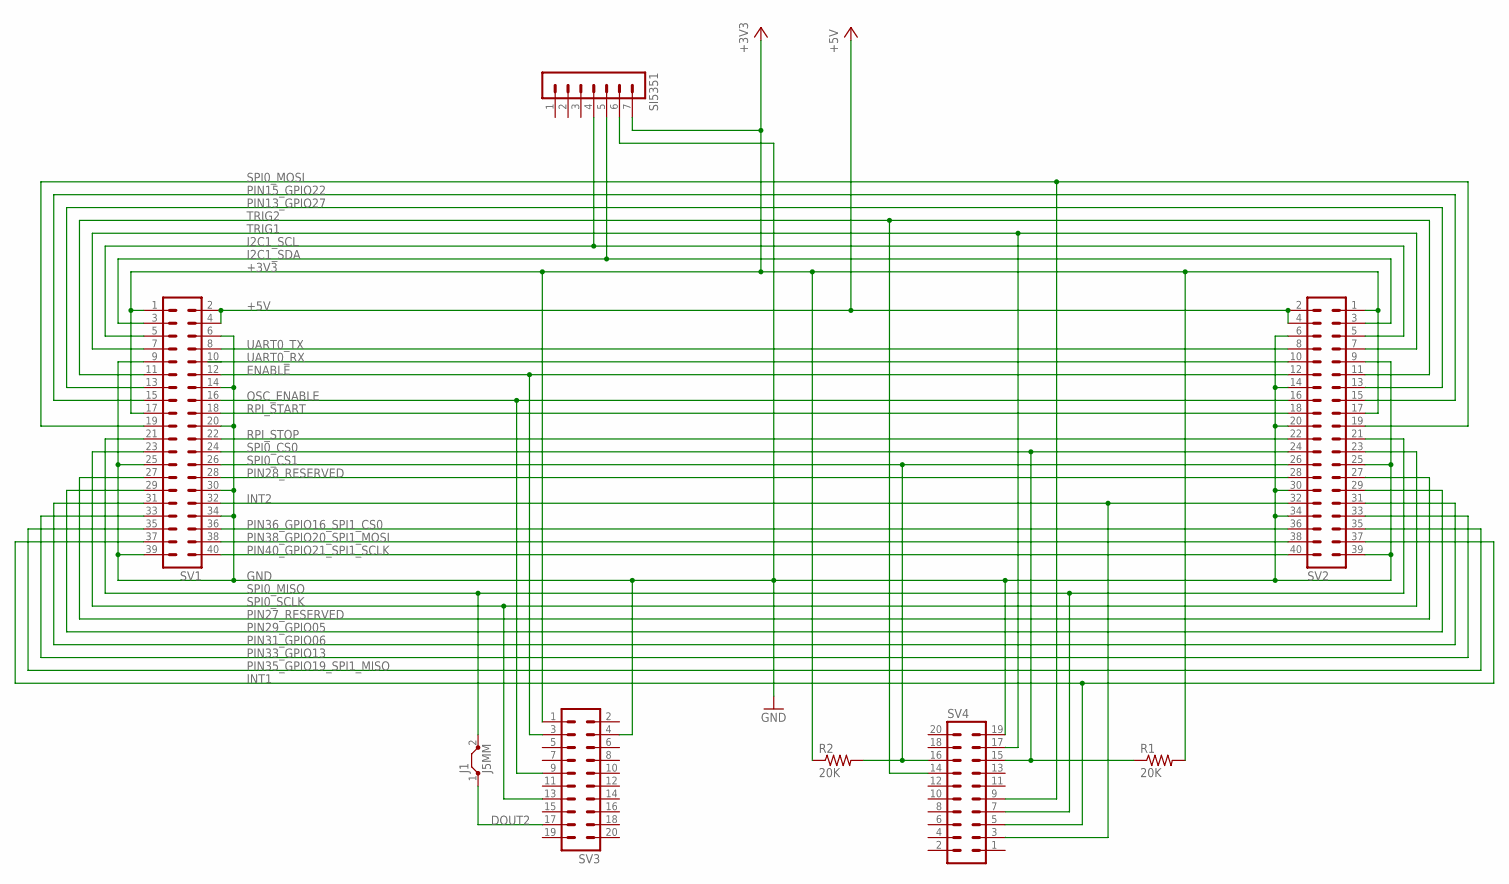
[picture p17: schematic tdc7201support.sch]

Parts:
J1: J5MM; 05
R1, R2: 20K; 0617/22
SI5351: MA07-1
SV1, SV2: MA20-2
SV3, SV4: MA10-2

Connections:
+3V3: R1.2, R2.1, SI5351.7, SV1.1, SV1.17, SV2.1, SV2.17, SV3.1
+5V: SV1.2, SV1.4, SV2.2, SV2.4
DOUT2: J1.1, SV3.17
ENABLE: SV1.12, SV2.12, SV3.3
GND: SI5351.6, SV1.6, SV1.9, SV1.14, SV1.20, SV1.25, SV1.30, SV1.34, SV1.39, SV2.6, SV2.9, SV2.14, SV2.20, SV2.25, SV2.30, SV2.34, SV2.39, SV3.4, SV4.19
I2C1_SCL: SI5351.4, SV1.5, SV2.5
I2C1_SDA: SI5351.5, SV1.3, SV2.3
INT1: SV1.37, SV2.37, SV4.5
INT2: SV1.32, SV2.32, SV4.3
OSC_ENABLE: SV1.16, SV2.16, SV3.9
PIN13_GPIO27: SV1.13, SV2.13
PIN15_GPIO22: SV1.15, SV2.15
PIN27_RESERVED: SV1.27, SV2.27
PIN28_RESERVED: SV1.28, SV2.28
PIN29_GPIO05: SV1.29, SV2.29
PIN31_GPIO06: SV1.31, SV2.31
PIN33_GPIO13: SV1.33, SV2.33
PIN35_GPIO19_SPI1_MISO: SV1.35, SV2.35
PIN36_GPIO16_SPI1_CS0: SV1.36, SV2.36
PIN38_GPIO20_SPI1_MOSI: SV1.38, SV2.38
PIN40_GPIO21_SPI1_SCLK: SV1.40, SV2.40
RPI_START: SV1.18, SV2.18
RPI_STOP: SV1.22, SV2.22
SPI0_CS0: R1.1, SV1.24, SV2.24, SV4.15
SPI0_CS1: R2.2, SV1.26, SV2.26, SV4.16
SPI0_MISO: J1.2, SV1.21, SV2.21, SV4.7
SPI0_MOSI: SV1.19, SV2.19, SV4.9
SPI0_SCLK: SV1.23, SV2.23, SV3.13
TRIG1: SV1.7, SV2.7, SV4.17
TRIG2: SV1.11, SV2.11, SV4.14
UART0_RX: SV1.10, SV2.10
UART0_TX: SV1.8, SV2.8

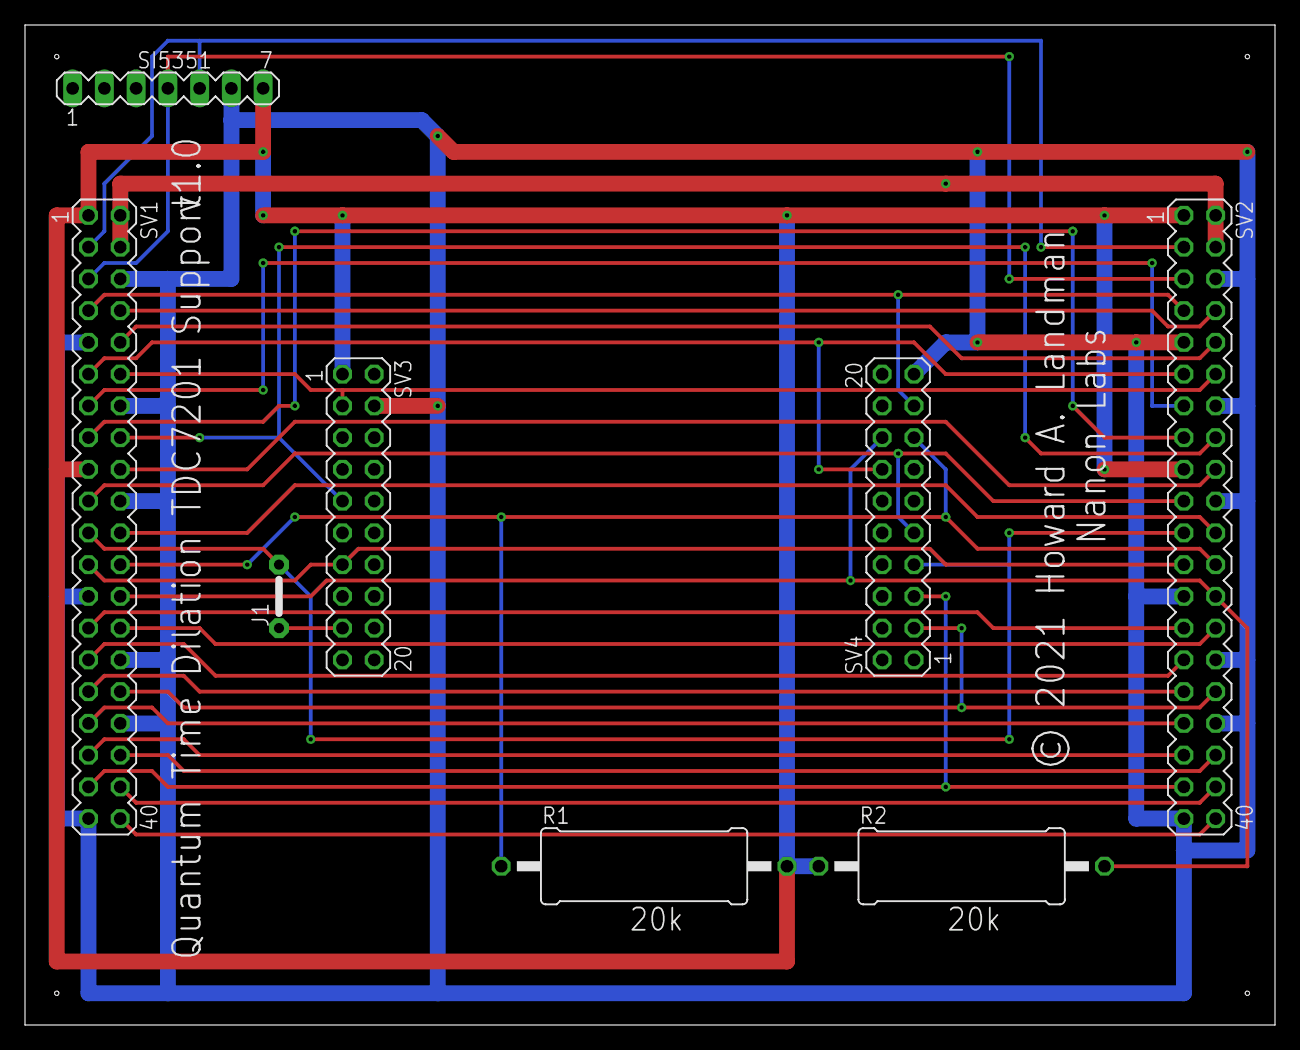
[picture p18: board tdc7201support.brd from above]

Board: 2 copper layers, 100.0 x 80.0 mm, 8 parts (0 on the bottom side), 32 nets.

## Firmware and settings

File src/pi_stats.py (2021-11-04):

#!/usr/bin/python3
"""Publish Raspberry Pi status, updating once per minute."""

import time
import os
import signal
import sys
import socket
import paho.mqtt.client as mqtt

# Handle ^C keyboard interrupt.
def sigint_handler(sig, frame):
    """Exit as gracefully as possible."""
    sys.exit(0)

signal.signal(signal.SIGINT, sigint_handler)

# I2C bus devices
import board
import busio
import adafruit_si5351
import adafruit_ads1x15.ads1115 as ADS
from adafruit_ads1x15.analog_in import AnalogIn
i2c = busio.I2C(board.SCL, board.SDA)
#
# Si5351 clock generator, i2c address 0x60
# Used to generate 16 MHz clock for the tdc7201.
try:
    si5351 = adafruit_si5351.SI5351(i2c)	# may throw ValueError
    print('Si5351: Device found.')
    # Only needs to be initialized once, so may as well do it here.
    # Generate 16 MHz clock by 25 MHz x 16 / 25.
    print('Si5351: Input clock assumed to be 25 MHz.')
    # Configure multiplier (to PLL A).
    si5351.pll_a.configure_integer(16)
    print('Si5351: PLL A multiplier set to 16.')
    print('Si5351: PLL A set to {0} MHz'.format(si5351.pll_a.frequency / 1000000))
    # Configure divider (from PLL A).
    si5351.clock_1.configure_integer(si5351.pll_a, 25)
    print('Si5351: Clock 1 set to divide PLL A by 25.')
    print('Si5351: Clock 1 set to {0} MHz'.format(si5351.clock_1.frequency / 1000000))
    # Turn outputs on.
    si5351.outputs_enabled = True
    print('Si5351: Clock outputs enabled')
except ValueError:
    print('Si5351: ERROR: Device not found.')
    si5351 = None

# ads1115 4-channel 16-bit ADC, i2c address 0x48
# Used to monitor supply voltages
try:
    ads1115 = ADS.ADS1115(i2c)	# may throw ValueError
    print('ads1115: Device found.')
    #ads1115.mode = Mode.SINGLE	# in Adafruit code, but doesn't work
    ads1115.gain = 1
    voltage5v0 = AnalogIn(ads1115, ADS.P0)	# RPi 5V rail
    voltage3v7 = AnalogIn(ads1115, ADS.P1)	# lithium battery 3.7V
    voltage3v3 = AnalogIn(ads1115, ADS.P2)	# RPi 3.3V rail
except ValueError:
    print('ads1115: ERROR: Device not found.')
    ads1115 = None

# MQTT stuff.
#MQTT_SERVER_NAME = "mqtt.eclipse.org"
MQTT_SERVER_NAME = "test.mosquitto.org"

def on_connect(mqtt_client, userdata, flags, result_code):
    """MQTT callback for when the client receives a CONNACK response from the server."""
    print("Connected to", MQTT_SERVER_NAME, "with result code", result_code)
    # Any subscribes should go here, so they get re-subscribed on a reconnect.

def on_disconnect(mqtt_client, userdata, rc):
    print("MQTT disconnected with code", rc, ". Attempting to reconnect.")
    try:
        mqttc.reconnect()
    except socket.error:
        print("Reconnect failed, exiting.")
        sys.exit(0)

mqttc = mqtt.Client()
mqttc.on_connect = on_connect
mqttc.on_disconnect = on_disconnect
mqttc.connect(MQTT_SERVER_NAME, 1883, 300)

def publish_uname():
    """Publish uname() data to the MQTT server."""
    # What hardware are we running on?
    uname = os.uname()
    nodename = uname.nodename
    machine = uname.machine
    sysname = uname.sysname
    release = uname.release
    version = uname.version
    mqttc.publish(topic="QTD/VDDG/"+nodename+"/nodename",
                   payload=nodename, retain=True)
    mqttc.publish(topic="QTD/VDDG/"+nodename+"/machine",
                   payload=machine, retain=True)
    mqttc.publish(topic="QTD/VDDG/"+nodename+"/OS",
                   payload=sysname+" "+release+" "+version, retain=True)

cpu_temp = None
def publish_cpu_temp(f_name="/sys/class/thermal/thermal_zone0/temp"):
    """Publish the CPU temperature to the MQTT server."""
    global cpu_temp
    try:
        with open(f_name) as cpu_temp_file:
            temp_line = list(cpu_temp_file)[0]
    except IOError:
        print("Couldn't open", cpu_temp_file)
    else:
        # Smooth
        new_temp = int(temp_line)
        if cpu_temp is None:
            cpu_temp = new_temp
            #print("New temp =", cpu_temp/1000)
        else:
            cpu_temp = (3*cpu_temp + new_temp) / 4
            #print("Averaged temp =", cpu_temp/1000)
        rounded = round(cpu_temp/1000, 1)
        #print("CPU temp =", rounded)
    mqttc.publish(topic="QTD/VDGG/CPU/cpu_temp", payload=rounded)

def publish_gpu_temp(cmd="vcgencmd measure_temp"):
    """Publish the GPU temperature to the MQTT server."""
    try:
        with os.popen(cmd) as pipe:
            gpu_temp = pipe.read()[5:9]
    except IOError:
        print("Running", cmd, "failed.")
        gpu_temp = "Failed"
    else:
        #print("GPU temp =", gpu_temp)
        pass
    mqttc.publish(topic="QTD/VDGG/CPU/gpu_temp", payload=gpu_temp)

def publish_os_name():
    """Publish the OS name to the MQTT server."""
    # Get "pretty" OS name
    try:
        fname = '/etc/os-release'
        with open(fname) as f:
            os_name = f.read().split('"')[1] + ' '
    except IOError:
        print("Couldn't open", fname)
        os_name = 'unknown '
    # Get exact version-date.
    try:
        fname = "/etc/rpi-issue"
        with open(fname) as f:
            os_name += f.read().split()[3]
    except IOError:
        print("Couldn't open", fname)
        os_name += "XXXX-XX-XX"
    #print("OS name =", os_name)
    mqttc.publish(topic="QTD/VDDG/CPU/os_name", payload=os_name, retain=True)

def publish_cpu_info(f_name="/proc/cpuinfo"):
    """Publish the Raspberry Pi type name to the MQTT server."""
    try:
        with open(f_name) as cpu_info_file:
            hw_list = list(cpu_info_file)[-4:]
    except IOError:
        print("Couldn't open", cpu_info_file)
    else:
        for line in hw_list:
            #print(line, end='')
            hw_pair = line.split()
            if len(hw_pair) >= 2:
                topic = "QTD/VDDG/CPU/"+hw_pair[0]
                #print(topic)
                mqttc.publish(topic=topic, payload=" ".join(hw_pair[2:]), retain=True)

def publish_disk_space(fs="/",name="root"):
    """Publish filesystem fullness to the MQTT server."""
    cmd="df " + fs
    size = None
    used = None
    try:
        with os.popen(cmd) as pipe:
            words = list(pipe)[1].split()
            size = words[1]
            used = words[2]
            full_pct = round((int(used)/int(size))*100.0,3)
            #print("Disk", fs, full_pct, "percent full")
    except IOError:
        print("Running", cmd, "failed.")
    #except ValueError:
        #pass
    mqttc.publish(topic="QTD/VDGG/CPU/"+name, payload=str(full_pct))

def publish_load_avg(cmd="uptime"):
    """Publish the load average to the MQTT server."""
    try:
        with os.popen(cmd) as pipe:
            load = pipe.read().split(':')[-1].split(',')[0]
    except IOError:
        print("Running", cmd, "failed.")
        load = "Failed"
    else:
        #print("Load average =", load)
        pass
    mqttc.publish(topic="QTD/VDGG/CPU/load", payload=load)

def publish_voltages():
    if ads1115 is None:
        #print("No ads1115 found.")
        return None
    try:
        v = voltage5v0.voltage	# May throw OSError if i2c bus problem.
        mqttc.publish(topic="QTD/VDGG/CPU/5v0", payload='{:.5f}'.format(v))
    except OSError:
        # Measurement failed due to bus error?
        print("5v0 measurement failed due to OSError.")
    try:
        v = voltage3v7.voltage	# May throw OSError if i2c bus problem.
        mqttc.publish(topic="QTD/VDGG/CPU/3v7", payload='{:.5f}'.format(v))
    except OSError:
        # Measurement failed due to bus error?
        print("3v7 measurement failed due to OSError.")
    try:
        v = voltage3v3.voltage	# May throw OSError if i2c bus problem.
        mqttc.publish(topic="QTD/VDGG/CPU/3v3", payload='{:.5f}'.format(v))
    except OSError:
        # Measurement failed due to bus error?
        print("3v3 measurement failed due to OSError.")

publish_uname()
publish_os_name()
publish_cpu_info()

while True:
    mqttc.loop()
    publish_cpu_temp()
    publish_load_avg()
    publish_disk_space()
    publish_disk_space(fs="/mnt/qtd", name="data")
    publish_voltages()
    time.sleep(60)

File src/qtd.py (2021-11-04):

#!/usr/bin/python3
"""Run the (real or simulated) QTD experiment on a SPI-attached TDC7201 chip."""

import time
import os
import resource
import signal
import sys
import socket	# just for exception handling
import json
import paho.mqtt.client as mqtt
import tdc7201


# Handle ^C keyboard interrupt.
def sigint_handler(sig, frame):
    """Exit as gracefully as possible."""
    print('\nCaught SIGINT')
    payload = "SIGINT - interrupted (probably by keyboard ^C)"
    try:
        tdc.cleanup()
    except NameError:
        pass
    else:
        payload = "OFF"
    mqttc.publish(topic="QTD/VDDG/tdc7201/runstate", payload=payload)
    sys.exit(0)

signal.signal(signal.SIGINT, sigint_handler)


# MQTT stuff.
#MQTT_SERVER_NAME = "mqtt.eclipse.org"
MQTT_SERVER_NAME = "test.mosquitto.org"

def on_connect(mqtt_client, userdata, flags, result_code):
    """MQTT callback for when the client receives a CONNACK response from the server."""
    print("Connected to", MQTT_SERVER_NAME, "with result code", result_code)
    # Any subscribes should go here, so they get re-subscribed on a reconnect.

def on_disconnect(mqtt_client, userdata, rc):
    """MQTT callback for when the client is disconnected from the server."""
    print("MQTT disconnected with code", rc, ". Attempting to reconnect.")
    try:
        mqttc.reconnect()
    except socket.error:
        print("Reconnect failed, exiting.")
        sys.exit(0)

mqttc = mqtt.Client()
mqttc.on_connect = on_connect
mqttc.on_disconnect = on_disconnect
try:
    mqttc.connect(MQTT_SERVER_NAME, 1883, 600)
except socket.gaierror:
    print("ERROR: getaddrinfo() failed. Couldn't connect to MQTT server", MQTT_SERVER_NAME+".")
    print("MQTT status logging will not work!!!")

def publish_tdc7201_driver():
    """Publish the version number of the TDC7201 driver to the MQTT server."""
    try:
        # the fast easy way
        driver = tdc7201.__version__	# exists in versions 0.6b1 and later
    except AttributeError:
        # This is grotesquely slow, but should work with any version
        command = "python3 -m pip show tdc7201 | grep Version"
        try:
            with os.popen(command) as pipe:
                driver = pipe.read().split()[1]
        except IOError:
            driver = "unknown"
    print("TDC7201 driver version =", driver)
    mqttc.publish(topic="QTD/VDGG/tdc7201/driver", payload=driver)

tdc = tdc7201.TDC7201()	# Create TDC object with SPI interface.

# Set RPi pin directions and default values for non-SPI signals.
# Pin assignments should stay the same for entire run.
# This also puts the chip into reset ("off") state.
tdc.initGPIO()

# Setting and checking clock speed.
tdc.set_SPI_clock_speed(25000000)	# 25 MHz is spec max

# Internal timing
now = time.time()
print("Current time (UTC):", time.asctime(time.gmtime(now)))
print("Current time (local):", time.asctime(time.localtime(now)), time.strftime("%Z"))
publish_tdc7201_driver()

# Turn the chip on and configure it.
tdc.on()
NUM_STOP = 3	# We check against this later.
tdc.configure(side=1, meas_mode=2, num_stop=NUM_STOP, clock_cntr_stop=0, timeout=0.000165, calibration2_periods=40)
mqttc.publish(topic="QTD/VDDG/tdc7201/runstate", payload="ON")

# Make sure our internal copy of the register state is up to date.
#print("Reading chip side #1 register state:")
tdc.read_regs()
#tdc.print_regs1()

batches = -1	# number of batches, negative means run forever
ITERS = 100000 # measurements per batch
mqttc.publish(topic="QTD/VDDG/tdc7201/batchsize", payload=str(ITERS))
#RESULT_NAME = ("0", "1", "2", "3", "4", "5",
#               "No calibration", "INT1 fall timeout", "TRIG1 fall timeout",
#               "INT1 early", "TRIG1 rise timeout", "START_MEAS active",
#               "TRIG1 active", "INT1 active")
cum_results = [0, 0, 0, 0, 0, 0, 0, 0, 0, 0, 0, 0, 0, 0]
result_list = [0, 0, 0, 0, 0, 0, 0, 0, 0, 0, 0, 0, 0, 0]

now = time.time()
while batches != 0:
    print("batches =", batches)
    mqttc.loop()
    # Measure average time per measurement.
    then = now
    timestamp = time.strftime("%Y%m%d%H%M%S")
    #print(timestamp)
    data_fname = '/mnt/qtd/data/' + timestamp + ".txt"
    try:
        data_file = open(data_fname,'w')
        data_file.write("QTD experiment data file\n")
        data_file.write("Time : " + str(then) + "\n")
        data_file.write("Date : " + timestamp + "\n")
        data_file.write("Batch : " + str(abs(batches)) + "\n")	# NOT CORRECT for batches > 0 !
        data_file.write("Batch_size : " + str(ITERS) + "\n")
        data_file.write("Config : " + str(tdc.reg1[0:12]) + "\n")
    except (IOError, OSError):
        print("Couldn't open", data_fname, "for writing.")
        #tdc.cleanup()
        #sys.exit()
        data_file = None
    #result_list = [0, 0, 0, 0, 0, 0, 0, 0, 0, 0, 0, 0, 0, 0]
    for m in range(ITERS):
        m_str = str(m) + ' '
        result = tdc.measure(simulate=True, error_prefix=m_str, log_file=data_file)
        result_list[result] += 1
        if result==2:
            # Record results in microseconds
            #decay = 1000000 * (tdc.tof2 - tdc.tof1)
            # Record raw register data, so we can analyze differently later if needed,
            # as well as the computed delay between STOP1 and STOP2.
            #tof_line = m_str + str(tdc.reg1[0x10:0x1C]) + ' ' + str(decay) + '\n'
            tof_line = m_str + str(tdc.reg1[0x10:0x1C]) + '\n'
            if data_file:
                data_file.write(tof_line)
        elif result > NUM_STOP and result <= 5:
            print("ERROR: Too Many Pulses:", result, str(tdc.reg1[0x10:0x1D]))
    if data_file:
        data_file.write('Tot : ' + str(result_list) + "\n")
    PAYLOAD = json.dumps(result_list)
    print(PAYLOAD)
    mqttc.publish(topic="QTD/VDDG/tdc7201/batch", payload=PAYLOAD)
    now = time.time()
    DURATION = now - then
    #print(ITERS, "measurements in", DURATION, "seconds")
    #print((ITERS/DURATION), "measurements per second")
    #print((DURATION/ITERS), "seconds per measurement")
    pulse_pair_rate = result_list[2] / DURATION
    # MQTT "payload" = entire message, but
    # node-red "payload" = field inside message.
    # It's confusing.
    mqttc.publish(topic="QTD/VDDG/tdc7201/p2ps", payload=pulse_pair_rate)
    for i in range(len(result_list)):
        cum_results[i] += result_list[i]
        result_list[i] = 0
    if data_file:
        data_file.write('Cum : ' + str(cum_results) + "\n")
        data_file.close()
        data_file = None
    print(cum_results)
    #print('Memory usage: %s (kb)' % resource.getrusage(resource.RUSAGE_SELF).ru_maxrss)
    print(pulse_pair_rate, "valid measurements per second")

    batches -= 1

# Turn the chip off.
tdc.off()
mqttc.publish(topic="QTD/VDDG/tdc7201/runstate", payload="OFF")

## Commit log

2015-07-27 First thoughts on the Teachspin muon lifetime device, 2012/09/10 This was emailed to John Harton and Stuart Field.
2015-07-27 Full report on analysis of data from Teachspin device, 2012/11/03
2015-07-31 3D printing data for plate support.
    [plate_support_25_mm.stl]
2015-09-15 Initial commit of detector frame pieces.
    [detector_side.stl, detector_slot.stl, tolerance_vernier.stl]
2015-09-15 Allow for greater printing tolerance. (This is "Rev 2")
    [detector_side.stl]
2015-09-15 Redesign of slot structure to make slots through and wider. (This is "Rev 3".)
    [detector_side.stl]
2015-09-15 Initial commit of sphere support.
    [sphere_support.stl]
2015-09-17 Minor adjustments after first (partial, aborted) print. Make outer cylinder 0.2 mm smaller OD and 0.2 mm larger ID (it fit, but was pretty snug). Add fillet at flange join.
    [sphere_support.stl]
2015-09-20 Added inner flanges with cable guide holes. Increased outer wall ID (for VDGG tube OD) slightly. Slight change to bracket slot top lip.
    [sphere_support.stl]
2015-10-12 Sphere support, redesigned in FreeCAD for milling from 155 mm Delrin rod.
    [sphere_support_cyls3g.FCStd, sphere_support_cyls3g.step]
2015-10-12 Sphere support, same as cyls3g version except 160 mm base. For 3D printing, also broke into 8 octants or edges, and laid them down sideways for better tensile strength. (Wedges 7 and 8 are identical 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
    [sphere_support_cyls4.FCStd, sphere_support_cyls4_w1.FCStd, sphere_support_cyls4_w1.stl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]
2017-10-16 Python driver for Texas Instruments tdc7201 time-to-digital converter chip. Uses spidev library for SPI communications. Initial commit successfully reads and writes 8-bit registers. No class definiti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
2017-10-16 Rearranged to put DOUT2 with SPI signals. Added some comments.
2017-11-06 Added Foam Support
    Added a support structure to strengthen the foam board holding all the electronics. It uses a hyperboloid strut system, and is very strong. But it's quite large (over 400g of plastic), and warping can be a problem, especially using ABS. Print time on a Lulzbot Taz 5 was around 25 hours.
    [QTD Foam Support.scad, QTD Foam Support.stl]
2017-11-18 Finally found and fixed the bug that was corrupting SPI. Apparently Python 2.7 thought "2 >> 1" meant "write the integer 2 to device 1".
2017-12-01 Turned off some debugging print statements. Deleted spi_broken() since that bug was fixed. Added "_" in front of a few more class variables. This is now primary source; Python 2 version is secondary.
2017-12-01 Changed from "inheritance" (TDC7201 as a subclass of SpiDev) to "composition" (TDC7201 contains an instance of SpiDev), i.e. from "is a" to "has a". I think this is cleaner. Most direct access to SPI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
2017-12-03 Added foam support
    Added “QTD Foam Support”.
    Updated “QuantumTime.tex”.
    [QTD Foam Support.scad, QTD Foam Support.stl]
2020-03-31 Fixed "INTB1 still low" bug. Enhanced clear_status(). Call clear_status() after each measurement. Added status reporting to measure(). Collect status statistics. Added 22 uS timeout. Now getting abou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
2020-04-17 Increased SPI clock speed to max. Improved error message for when no TDC7201 is connected.
2020-04-23 Make tdc7201 code into an importable module. Break out non-library functionality into qtd.py. This version sort of works, but requires "import tdc7201.tdc7201 as tdc7201". Will try to fix that in nex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
    [qtd.py]
2020-05-03 Deleted unused top level code. Added exception handling in case SPI is not enabled or can't be opened.
2020-05-04 Fix and test exception handling when SPI interface is not enabled.
2020-05-04 Added calibration2_periods, avg_cycles, and num_stop arguments to on().
2020-05-06 Added arguments to initGPIO() so user can select pin assignments.
2020-05-06 Deleted extraneous print() in initGPIO().
2020-05-16 SPI speedup using auto-increment mode.
2020-05-16 Version 0.5b1 : SPI speedup and MQTT hooks
2020-05-21 Publish driver, os_name. Fix batch so node-red pie chart works.
    [qtd.py]
2020-05-22 Node-red flow for experiment dashboard. Works on Mac.
2020-05-28 Turn off some debug printing.
2020-05-29 Debugging temperature averaging.
2020-05-29 Massive de-linting. Use try-with-as for opening files and pipes.
2020-05-31 Fixed CPU temperature smoothing.
    [qtd.py]
2020-06-03 Added SIGINT handling for more graceful exit. Doesn't clean up GPIO yet.
    [qtd.py]
2020-06-05 Increased slot width 1 mm, decreased radius 1 mm, added filleting with 3 mm radius.
    [QTD Foam Support.scad]
2020-06-06 Shrink radius to fit on bed of FCCH Taz5.
    [QTD Foam Support.scad]
2020-06-10 Print a newline after keyboard interrupt before anything else.
2020-06-12 As printed at Prozix.
    [QTD Foam Support.scad]
2020-06-19 Partial de-linting of tdc7201/__init__.py. Some attribute names had to change, so changed qtd.py to match. Moved some constant code from compute_TOFs() to on(); this resulted in a ~6% speedup.
2020-06-24 Put try:except: around opening data files. Reorder measurement data lines. Run SPI at 30 MHz.
2020-06-24 Allow absolute max SPI speed of 33 MHz, with warning if over 25 MHz.
2020-07-10 Fixed crash in MQTT when can't connect to server. Inserted space in TOF line.
    [qtd.py]
2020-07-10 Revised docstrings. Made GPIO pin setup more consistent. Only send max NSTOP pulses during simulation.
2020-07-12 Cleaned up error printing in measure().
2020-07-12 Cleanup THEN and NOW. Allow prepending run # to error messages in measure().
    [qtd.py]
2020-07-12 Enable writing error messages to data file.
    [qtd.py]
2020-08-04 Require spidev>=3.5, as 3.4 had a Py_DECREF bug that could cause the program to die with "free(): invalid pointer" after 100M+ cycles.
2020-08-08 Changed "qtd-0w" to generic "CPU". Changed mount point for USB drive to /mnt/qtd.
2020-08-08 Changed USB drive mount point to /mnt/qtd. Reverted pulse_pair_rate to float.
    [qtd.py]
2020-09-07 pulse.py : added. qtd.py : Reworked TRIG handling to allow ignoring it when not simulating.
    [pulse.py, qtd.py]
2020-09-14 Refactored on() into on() and configure(). (This will make it easier to add side 2 support later.) Generate START pulses internally, leaving STOP external. Handle occasional failures to write config 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
    [qtd.py]
2020-09-29 Print error message for too many pulses.
    [qtd.py]
2020-10-02 Fixed off-by-1 list slicing in error message.
    [qtd.py]
2020-10-09 Return SPI clock speed to 25 MHz, since faster does not improve performance much.
2020-10-09 Update sample usage to use on() and configure() correctly.
2020-10-10 Don't print (just log) on error 6.
2020-10-10 Move printing pulse_pair_rate to very end (of measure()).
2020-10-17 Version 0.9.0 (switch to SemVer version numbers). Use GPIO.wait_for_edge() for INT1; slightly slower but much lower power.
2020-10-18 Cut measurement timeout to 165 uS.
2020-10-18 Changed temperature limits in CPU Temp Gauge to reflect thermal problems seen.
2020-11-23 Fix except condition when failing to open log file for writing.
    [qtd.py]
2020-12-03 First map of I2C bus device addresses.
2021-08-12 Eagle CAD schematic and layout for TDC7201 support board.
    [tdc7201support.brd, tdc7201support.sch]
2021-08-13 Added voltage tab and 3 voltage rail graphs. Changed some warning thresholds and colors.
2021-11-04 Show how to make node-red pretty print, and to uninstall tdc7201 lib if needed.
2021-11-04 Add support for I2C bus devices (Si5351 and ads1115). Report voltages if ads1115 present.
2021-11-04 v0.11.3. Support using side 2, external clock. Move interrupt wait time calculation out of main measure loop.

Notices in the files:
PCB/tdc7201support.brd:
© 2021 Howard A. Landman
